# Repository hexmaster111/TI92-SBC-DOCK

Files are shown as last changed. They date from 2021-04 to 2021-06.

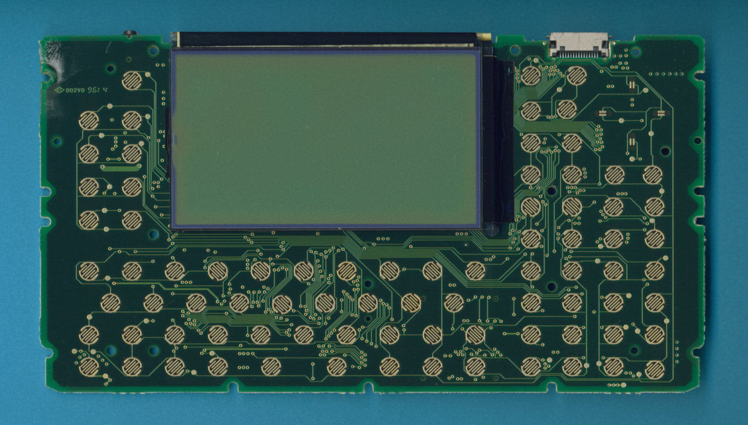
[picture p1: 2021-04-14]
TI-92_I0696_PCBA.jpg

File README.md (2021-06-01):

**NOTE**
The Zero version is not currently being worked on and is an unusable state

# TI92 - CM4

TODO
--------
- [ ] Whats gonna happon is im gonna get a 4 inch hdmi display and desolder the hdmi connector and add it to a ribbion cable and then add a connector to the pcb for hdmi to interface with that
- [ ] Add a SD card slot
- [x] Figure out what display to use
- [ ] Add a headphone port
- [x] Add a USB Hub
	- [ ] Route USB in a good way :wink:
- [x] Get a charge solution sorted
- [x] Figure out how the keyboard will work and talk to the pi
- [ ] TEST
- [ ] Write code for the ATTINY85 (aka power control chip)
	- [ ] ~~Find a better way to switch power?~~
 - [ ] Use the micro USB that is used for charging to also act as USB OTG for flashing the CM4
 - [ ] Figure out a low voltage cut off for the batCell+ line
 - [ ] Calculate R4 on the charge chip
 - [ ] Make sure all the components will fit in the case with there given footprints
	 - [ ] Measure for LEDS
		 - [ ] Drill Holes for indicators
		 - [ ] Make a nice overlay for indicators 
	 - [ ] Measure for USB Connections
		 - [ ] Modify case

Display
----------
The display being used is a 4 inch SPI display by waveshare and is connected with a pin header, I still have to get the part and check for fitmint for sure, but [this](https://www.waveshare.com/4inch-RPi-LCD-C.htm) looks prmissing

for the display, install accoring to waveshare https://www.waveshare.com/wiki/4inch_HDMI_LCD and deleate all the vc4 overlays and it works (somehow)

Battery Charging
----------
For charging two 18650s I'm using the BQ25887RGET Chip by TI. This chip should have enough current to keep the batteries charged in use. For power input I'm using a Micro USB 

USB Hub
-----------
For a USB hub I'm using the TUSB4041l by Texas instruments, this chip supports 4 downstream ports and 1 upstream, the upstream port is wired directly into the CM4's USB data lines. There are two ports that are connected to standard USB connectors. 

There is also one USB port left unused on the board for internal modifications later on. 

To Get this chip to work, I had to add a 3.3v power supply capable of suppling more current then the pi could, and added the +3.3 High Current Global net. 

To Get this chip to work, I had to add a 1v power supply capable of suppling more current then the pi could, and added the +1 Global net.

Making the keyboard work
----------------------------------
For a keyboard controller I chose to use a 5K5126 which is a programable keyboard controller that supports arbitrary key mapping along with macros and this is all done with a graphical program and uploaded to the keyboard. 
After uploading the matrix and stuff to the controller the idea is to then solder JP2 & JP3. This will then allow the keyboard to communicate with the hub controller and then into the CM4 modal
**note:**  The keyboard controller has some GPIO we can use for a backlight or indicator LEDs, I need to check this out more. 

Power Control
--------
The +5v will go high after the ON button on the keyboard is pressed, this is done using an ATTINY85 and a latching relay, this is done so that I can use this for other single board computers in the future.  
Here is some pseudo code to help understand the idea
```
Use a pin on the pi as a way to know if the system is on and if that pin goes low we disconnect the battery from the 5v converter

if power=off & PowerButton=on //Turn on +5v rail (ColdBoot)
	SETPIN goes high
	wait(50ms)
	SETPIN goes low
	wait(1min)

if PiOnPin=low & power=on  //Shutdown pi after power on pin goes low
	RESETPIN high
	Wait(50ms)
	RESETPIN low

if PiOnPin=high & power=on & PowerButton=on //Force Shutdown 
	if PowerButton = held for 10 sec
		RESETPIN high
		Wait(50ms)
		RESETPIN low	
```

Things to Add Perhaps
---------------------------
- A pointing device
	- A track ball or other pointing device like [this](https://shop.pimoroni.com/products/trackball-breakout). 
	- Perhaps a trackpad
	- Use the Lock/Pinch key as a the key for mouse keys and use the D-Pad as the key mouse
- Some way to have a nice GPIO pin header behind a door for a clean look
- A new keyboard overlay for 2nd keys and the green diamond keys
- Custom keycaps?! (Clear injections would be cool for backlighting)
- Perhaps a ti-92 plus emulator for it (just for fun)

Credits
------
I got the PCB and keyboard layout and matrix diagram from [here](https://github.com/ccadic/TI92-revive). 
Everything else was from the Digi key parts repo or I made.

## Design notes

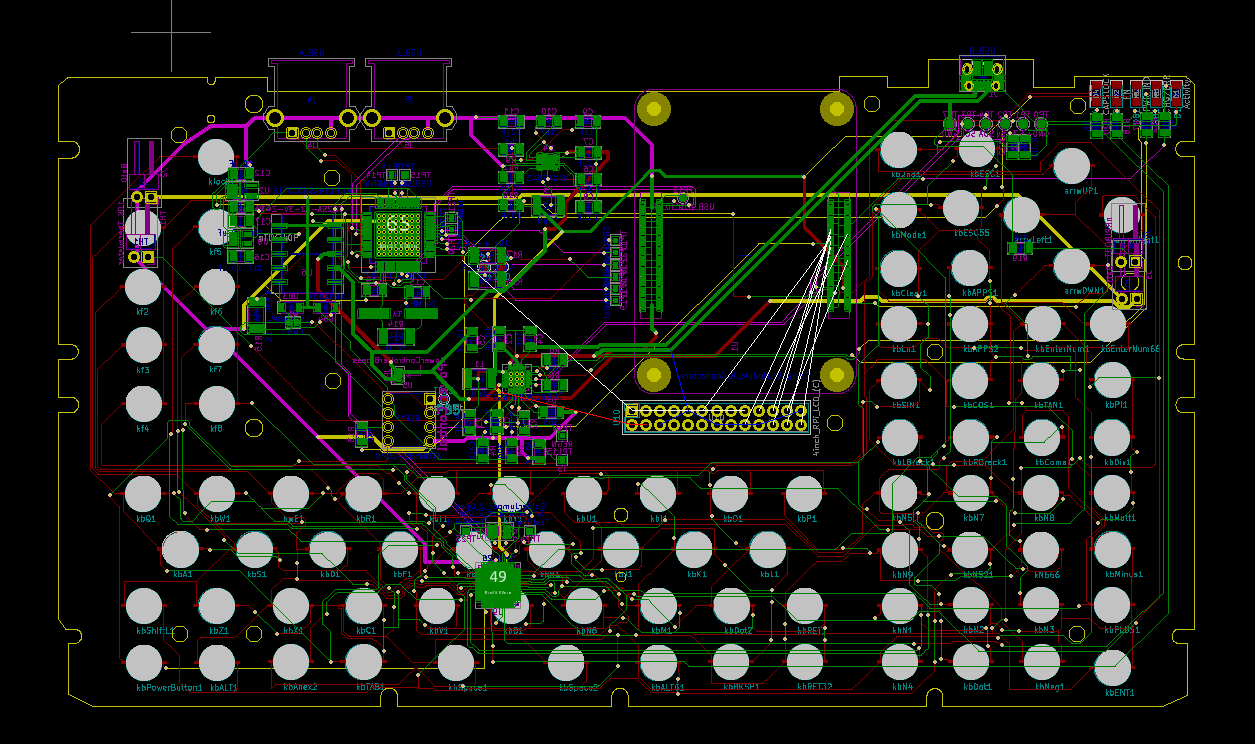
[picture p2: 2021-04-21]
CurrentProgress.PNG

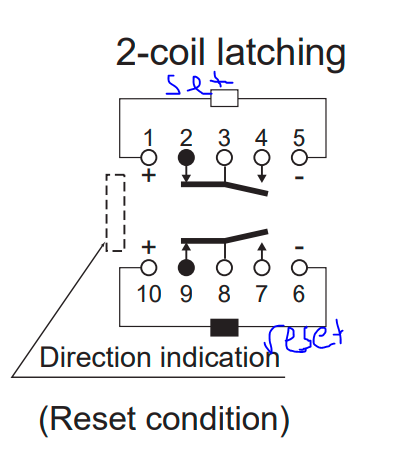
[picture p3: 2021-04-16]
CM4/DataSheets/RelaySnipFromDatasheet.PNG

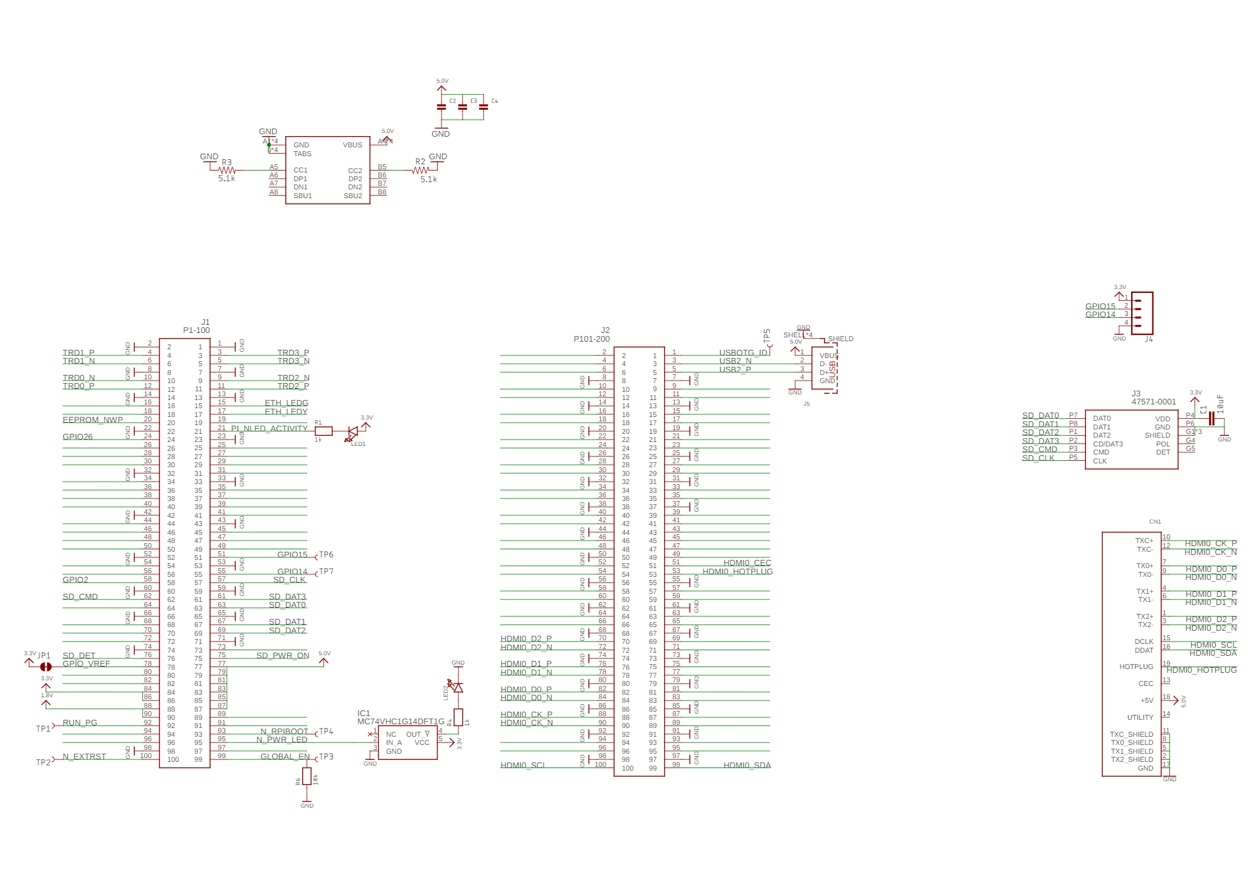
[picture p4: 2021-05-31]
CM4/DataSheets/simpleCM4 carrerer.png

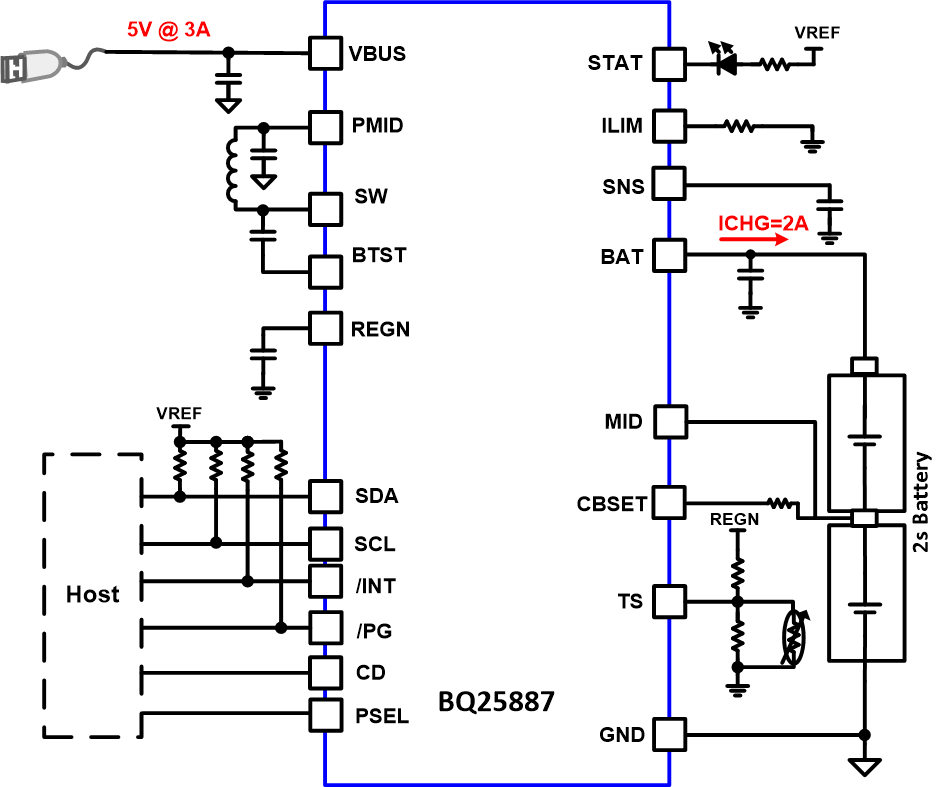
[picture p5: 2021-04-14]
CM4/DataSheets/fbd_slusd89b.gif

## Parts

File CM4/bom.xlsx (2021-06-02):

B2B-PH-K-S(LF)(SN)
PHR-2
SPH-002T-P0.5S
https://www.digikey.com/en/products/detail/bourns-inc/CC453232A-1R0KL/12756230
https://www.digikey.com/en/products/detail/texas-instruments/BQ25887RGET/10270194
10103594-0001LF | usb con
 |  |  | Magic Two Transistors for power
TPS61230DRCR (https://www.mouser.com/ProductDetail/Texas-Instruments/TPS61230DRCR?qs=p08Uhw9w2Fyn7hRbmC7n5A%3D%3D) |  |  | https://www.digikey.com/en/products/detail/rohm-semiconductor/EMH61T2R/5721184
 |  |  | Transistors for lcd
Power Control Tranistor |  |  | https://www.digikey.com/en/products/detail/on-semiconductor/NUS2401SNT1G/13442745
https://www.digikey.com/en/products/detail/goford-semiconductor/G6N02L/13664832
 |  |  | usb controller powersupply
https://www.digikey.com/en/products/detail/stewart-connector/SS-52100-001/7902377 |  |  | NCP114ASN330T1G
 |  |  | Usb controler
TQ2SA-L2-3V (https://www.mouser.com/ProductDetail/Panasonic-Industrial-Devices/TQ2SA-L2-3V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)
 |  |  | TUSB4041I-Q1 Four-Port USB 2.0 Hub | https://www.digikey.com/en/products/detail/citizen-finedevice-co-ltd/HCM4924000000ABJT/284293
 |  |  |  | Crystle
 |  | The display | 1v regulator
 |  | https://www.waveshare.com/4inch-RPi-LCD-C.htm | https://www.digikey.com/en/products/detail/texas-instruments/TLV74010PDBVR/12642176
 | Fan
 | https://www.digikey.com/en/products/detail/delta-electronics/BSB0205HP-00EFG/11201159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
 | sd con
 | https://www.digikey.com/en/products/detail/molex/5031821852/4693482

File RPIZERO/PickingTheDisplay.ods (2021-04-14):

Display | Width IN | Height IN | Angle size | Resulutinon | Price | Connection | Link
Stock 92+ | 3.5 | 1.9 | ~4 | low | free | in the calc
Pocket chip | 3.875 | 2.25 | ~4.5 | 480*272 | NA | Magic | Nope >.<
Ebay #1 | 3.85 | 2.28 | ~4 | 800*480 | 52.39 | HDMI | https://www.ebay.com/itm/Raspberry-Pi-4-Touchscreen-with-Case-Fan-4-inch-IPS-Touch-Screen-LCD-Display/363316412604

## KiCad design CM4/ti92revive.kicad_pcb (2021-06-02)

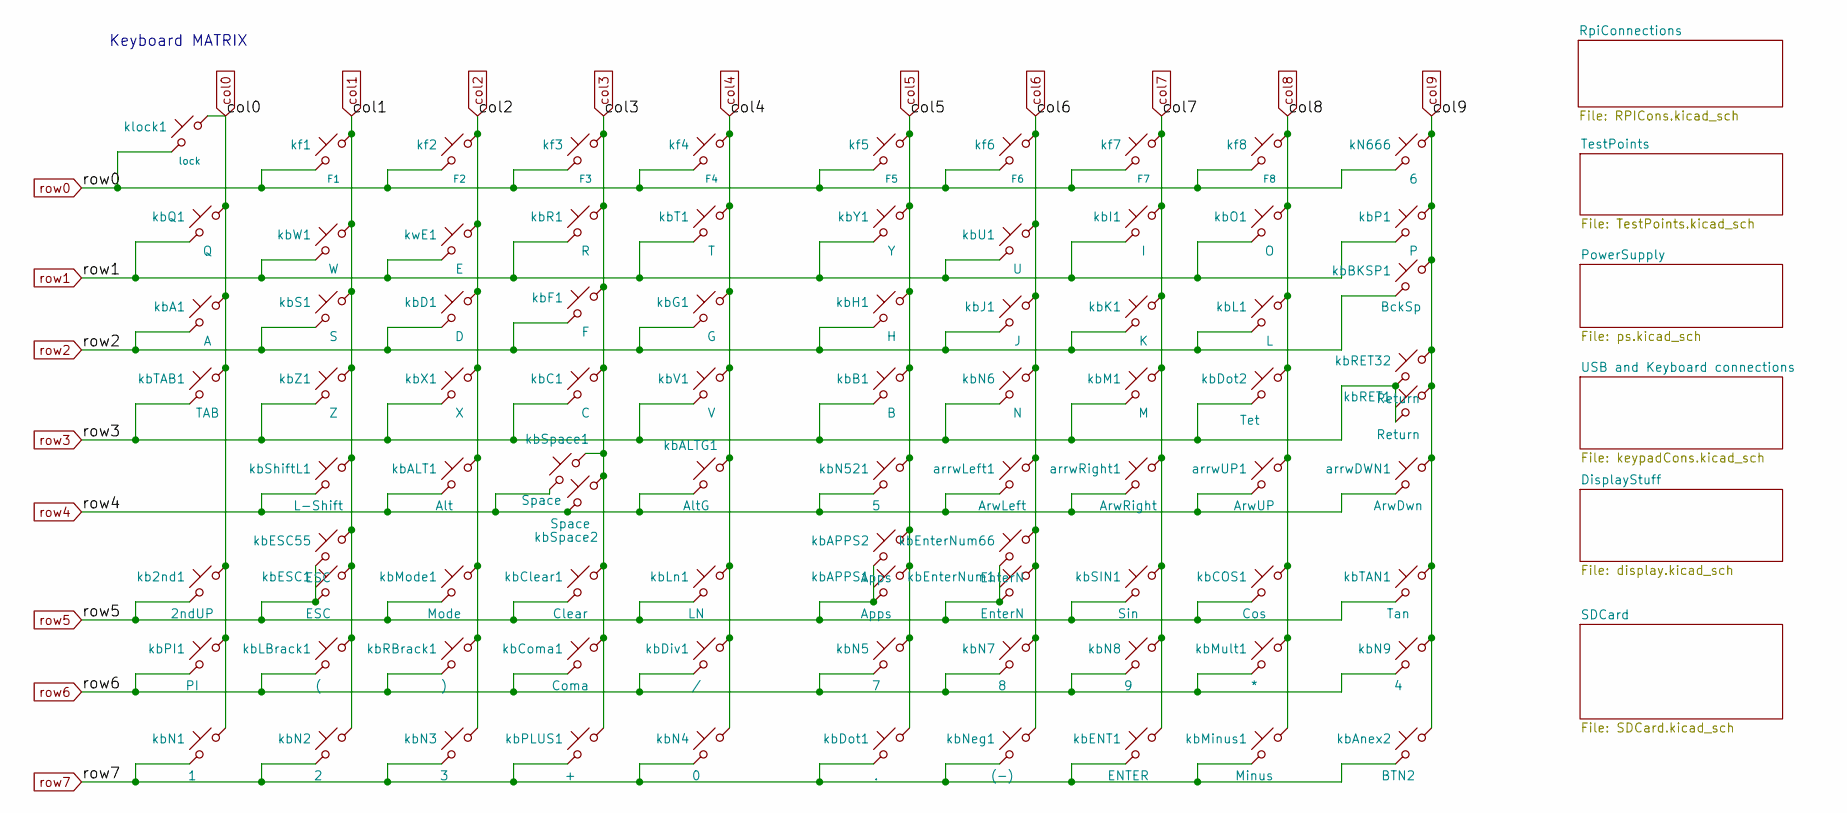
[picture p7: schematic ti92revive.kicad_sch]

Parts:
arrwDWN1: ArwDwn; Kbpad
arrwLeft1: ArwLeft; Kbpad
arrwRight1: ArwRight; Kbpad
arrwUP1: ArwUP; Kbpad
kN666: 6; Kbpad
kb2nd1: 2ndUP; Kbpad
kbA1: A; Kbpad
kbALT1: Alt; Kbpad
kbALTG1: AltG; Kbpad
kbAPPS1, kbAPPS2: Apps; Kbpad
kbAnex2: BTN2; Kbpad
kbB1: B; Kbpad
kbBKSP1: BckSp; Kbpad
kbC1: C; Kbpad
kbCOS1: Cos; Kbpad
kbClear1: Clear; Kbpad
kbComa1: Coma; Kbpad
kbD1: D; Kbpad
kbDiv1: /; Kbpad
kbDot1: .; Kbpad
kbDot2: Tet; Kbpad
kbENT1: ENTER; Kbpad
kbESC1, kbESC55: ESC; Kbpad
kbEnterNum1, kbEnterNum66: EnterN; Kbpad
kbF1: F; Kbpad
kbG1: G; Kbpad
kbH1: H; Kbpad
kbI1: I; Kbpad
kbJ1: J; Kbpad
kbK1: K; Kbpad
kbL1: L; Kbpad
kbLBrack1: (; Kbpad
kbLn1: LN; Kbpad
kbM1: M; Kbpad
kbMinus1: Minus; Kbpad
kbMode1: Mode; Kbpad
kbMult1: *; Kbpad
kbN1: 1; Kbpad
kbN2: 2; Kbpad
kbN3: 3; Kbpad
kbN4: 0; Kbpad
kbN5: 7; Kbpad
kbN6: N; Kbpad
kbN7: 8; Kbpad
kbN8: 9; Kbpad
kbN9: 4; Kbpad
kbN521: 5; Kbpad
kbNeg1: (-); Kbpad
kbO1: O; Kbpad
kbP1: P; Kbpad
kbPI1: PI; Kbpad
kbPLUS1: +; Kbpad
kbQ1: Q; Kbpad
kbR1: R; Kbpad
kbRBrack1: ); Kbpad
kbRET1, kbRET32: Return; Kbpad
kbS1: S; Kbpad
kbSIN1: Sin; Kbpad
kbShiftL1: L-Shift; Kbpad
kbSpace1, kbSpace2: Space; Kbpad
kbT1: T; Kbpad
kbTAB1: TAB; Kbpad
kbTAN1: Tan; Kbpad
kbU1: U; Kbpad
kbV1: V; Kbpad
kbW1: W; Kbpad
kbX1: X; Kbpad
kbY1: Y; Kbpad
kbZ1: Z; Kbpad
kf1: F1; Kbpad
kf2: F2; Kbpad
kf3: F3; Kbpad
kf4: F4; Kbpad
kf5: F5; Kbpad
kf6: F6; Kbpad
kf7: F7; Kbpad
kf8: F8; Kbpad
klock1: lock; Kbpad
kwE1: E; Kbpad

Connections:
col0: kb2nd1.1, kbA1.1, kbN1.1, kbPI1.1, kbQ1.1, kbTAB1.1, klock1.1; also elsewhere on the board
col1: kbESC1.1, kbESC55.1, kbLBrack1.1, kbN2.1, kbS1.1, kbShiftL1.1, kbW1.1, kbZ1.1, kf1.1; also elsewhere on the board
col2: kbALT1.1, kbD1.1, kbMode1.1, kbN3.1, kbRBrack1.1, kbX1.1, kf2.1, kwE1.1; also elsewhere on the board
col3: kbC1.1, kbClear1.1, kbComa1.1, kbF1.1, kbPLUS1.1, kbR1.1, kbSpace1.1, kbSpace2.1, kf3.1; also elsewhere on the board
col4: kbALTG1.1, kbDiv1.1, kbG1.1, kbLn1.1, kbN4.1, kbT1.1, kbV1.1, kf4.1; also elsewhere on the board
col5: kbAPPS1.1, kbAPPS2.1, kbB1.1, kbDot1.1, kbH1.1, kbN5.1, kbN521.1, kbY1.1, kf5.1; also elsewhere on the board
col6: arrwLeft1.1, kbEnterNum1.1, kbEnterNum66.1, kbJ1.1, kbN6.1, kbN7.1, kbNeg1.1, kbU1.1, kf6.1; also elsewhere on the board
col7: arrwRight1.1, kbENT1.1, kbI1.1, kbK1.1, kbM1.1, kbN8.1, kbSIN1.1, kf7.1; also elsewhere on the board
col8: arrwUP1.1, kbCOS1.1, kbDot2.1, kbL1.1, kbMinus1.1, kbMult1.1, kbO1.1, kf8.1; also elsewhere on the board
col9: arrwDWN1.1, kN666.1, kbAnex2.1, kbBKSP1.1, kbN9.1, kbP1.1, kbRET1.1, kbRET32.1, kbTAN1.1; also elsewhere on the board
row0: kN666.2, kf1.2, kf2.2, kf3.2, kf4.2, kf5.2, kf6.2, kf7.2, kf8.2, klock1.2; also elsewhere on the board
row1: kbI1.2, kbO1.2, kbP1.2, kbQ1.2, kbR1.2, kbT1.2, kbU1.2, kbW1.2, kbY1.2, kwE1.2; also elsewhere on the board
row2: kbA1.2, kbBKSP1.2, kbD1.2, kbF1.2, kbG1.2, kbH1.2, kbJ1.2, kbK1.2, kbL1.2, kbS1.2; also elsewhere on the board
row3: kbB1.2, kbC1.2, kbDot2.2, kbM1.2, kbN6.2, kbRET1.2, kbRET32.2, kbTAB1.2, kbV1.2, kbX1.2, kbZ1.2; also elsewhere on the board
row4: arrwDWN1.2, arrwLeft1.2, arrwRight1.2, arrwUP1.2, kbALT1.2, kbALTG1.2, kbN521.2, kbShiftL1.2, kbSpace1.2, kbSpace2.2; also elsewhere on the board
row5: kb2nd1.2, kbAPPS1.2, kbAPPS2.2, kbCOS1.2, kbClear1.2, kbESC1.2, kbESC55.2, kbEnterNum1.2, kbEnterNum66.2, kbLn1.2, kbMode1.2, kbSIN1.2, kbTAN1.2; also elsewhere on the board
row6: kbComa1.2, kbDiv1.2, kbLBrack1.2, kbMult1.2, kbN5.2, kbN7.2, kbN8.2, kbN9.2, kbPI1.2, kbRBrack1.2; also elsewhere on the board
row7: kbAnex2.2, kbDot1.2, kbENT1.2, kbMinus1.2, kbN1.2, kbN2.2, kbN3.2, kbN4.2, kbNeg1.2, kbPLUS1.2; also elsewhere on the board

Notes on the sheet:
Keyboard MATRIX

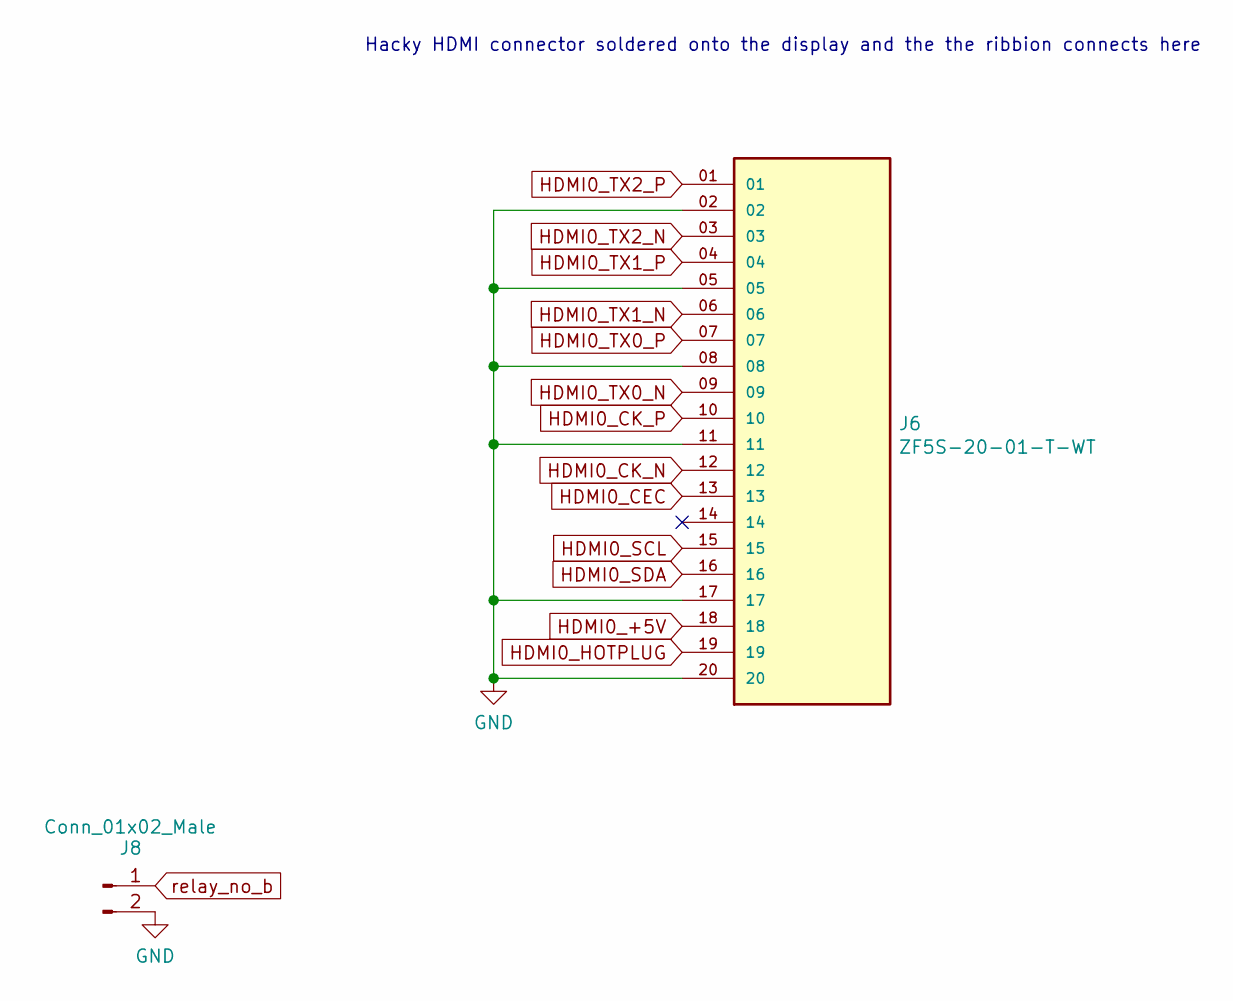
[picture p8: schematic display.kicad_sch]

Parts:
J6: ZF5S-20-01-T-WT; SAMTEC_ZF5S-20-01-T-WT
J8: Conn_01x02_Male; PinHeader_1x02_P1.00mm_Vertical

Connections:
Earth_Clean: J6.02, J6.05, J6.08, J6.11, J6.17, J6.20, J8.2; also elsewhere on the board
HDMI0_+5V: J6.18
HDMI0_CEC: J6.13; also elsewhere on the board
HDMI0_CK_N: J6.12; also elsewhere on the board
HDMI0_CK_P: J6.10; also elsewhere on the board
HDMI0_HOTPLUG: J6.19; also elsewhere on the board
HDMI0_SCL: J6.15; also elsewhere on the board
HDMI0_SDA: J6.16; also elsewhere on the board
HDMI0_TX0_N: J6.09; also elsewhere on the board
HDMI0_TX0_P: J6.07; also elsewhere on the board
HDMI0_TX1_N: J6.06; also elsewhere on the board
HDMI0_TX1_P: J6.04; also elsewhere on the board
HDMI0_TX2_N: J6.03; also elsewhere on the board
HDMI0_TX2_P: J6.01; also elsewhere on the board
relay_no_b: J8.1; also elsewhere on the board

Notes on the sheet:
Hacky HDMI connector soldered onto the display and the the ribbion connects here

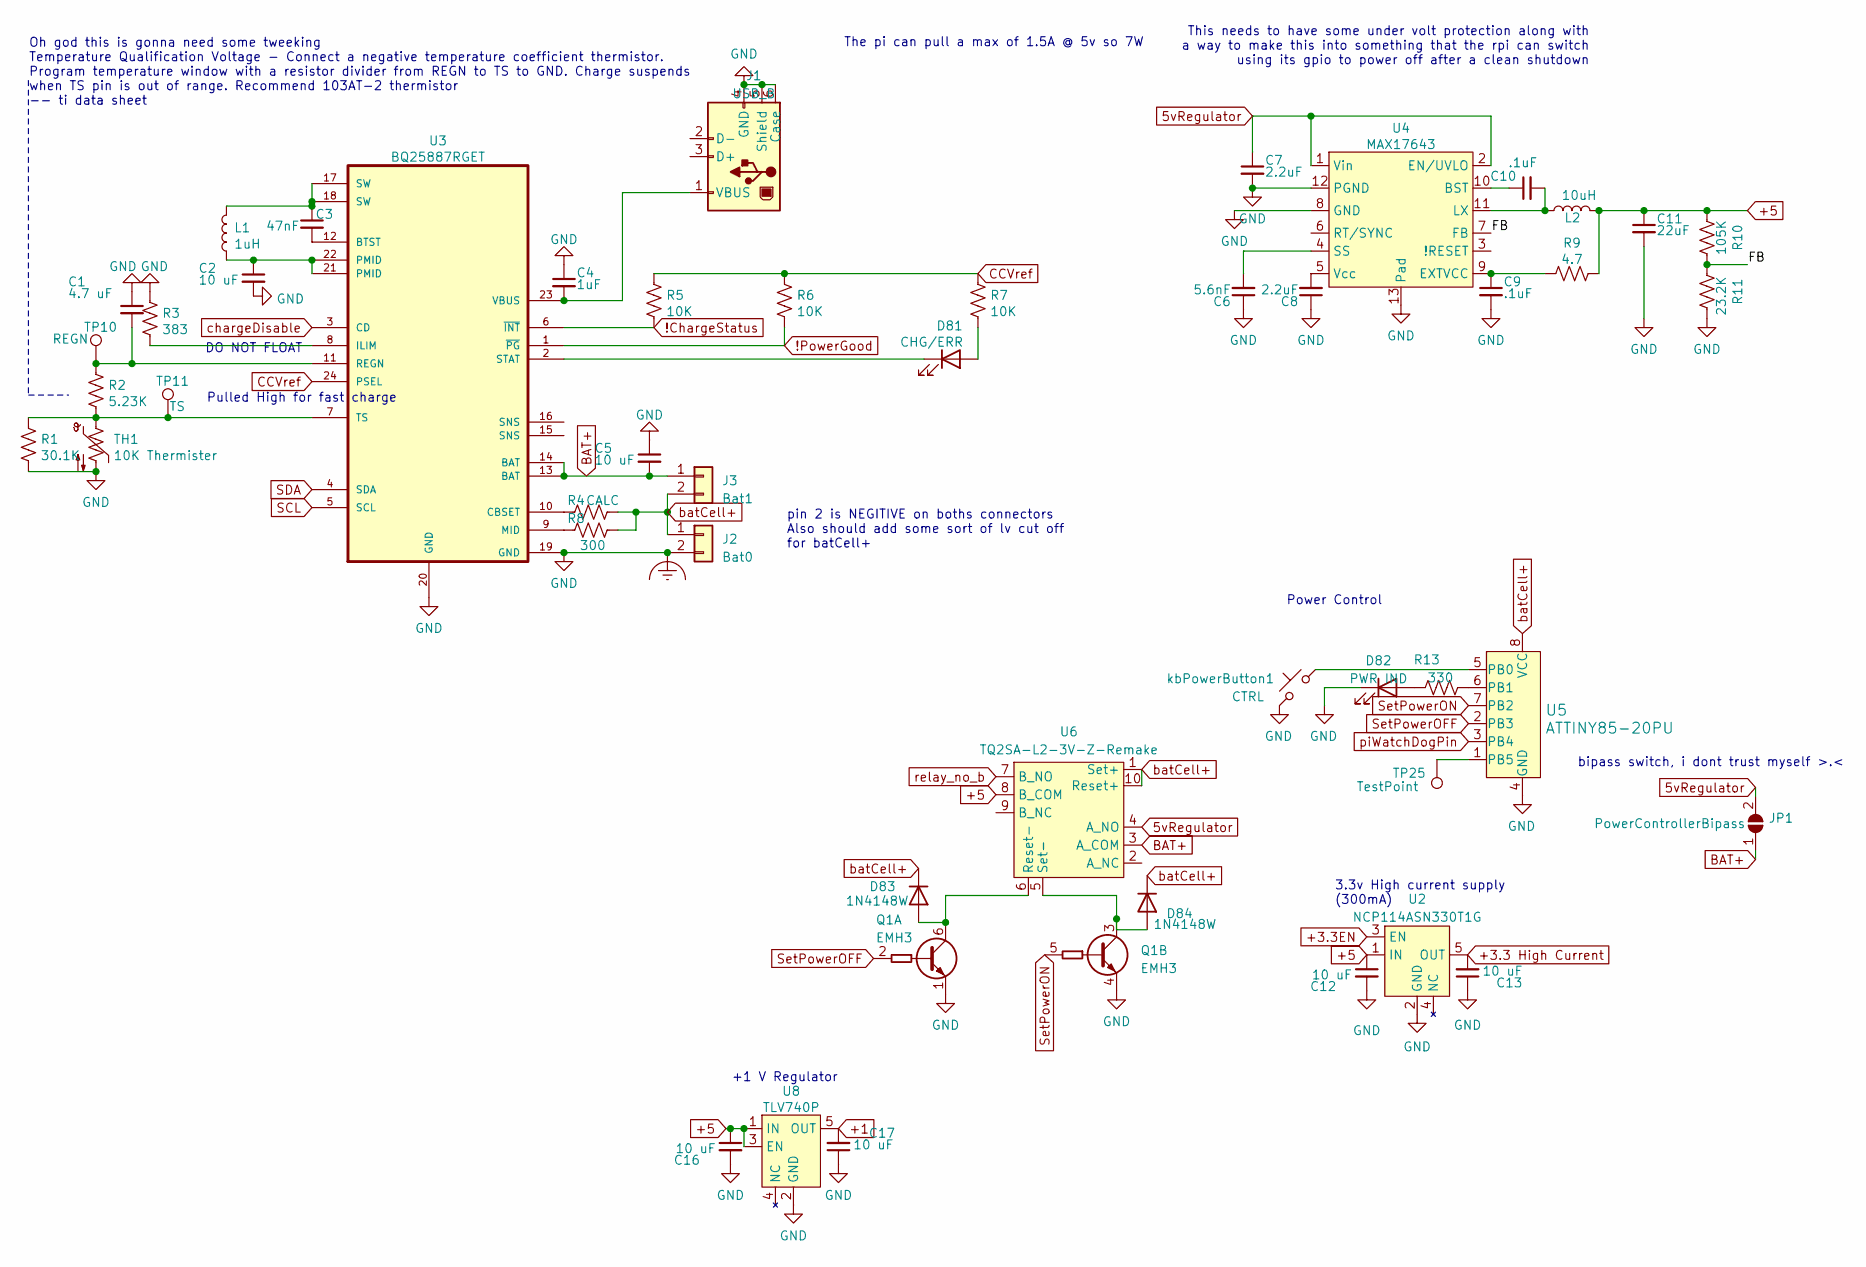
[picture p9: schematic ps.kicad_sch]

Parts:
C1: 4.7 uF; C_1206_3216Metric
C2, C5, C12, C13, C16, C17: 10 uF; C_1206_3216Metric
C3: 47nF; C_1206_3216Metric
C4: 1uF; C_1206_3216Metric
C6: 5.6nF; C_1206_3216Metric
C7, C8: 2.2uF; C_1206_3216Metric
C9, C10: .1uF; C_1206_3216Metric
C11: 22uF; C_1206_3216Metric
D81: CHG/ERR; LED_1206_3216Metric_Pad1.42x1.75mm_HandSolder
D82: PWR IND; LED_1206_3216Metric_Pad1.42x1.75mm_HandSolder
D83, D84: 1N4148W; D_SOD-123
J1: USB_B; USB_Micro-B_Amphenol_10103594-0001LF_Horizontal
J2: Bat0; PinHeader_1x02_P2.54mm_Horizontal
J3: Bat1; PinHeader_1x02_P2.54mm_Horizontal
JP1: PowerControllerBipass; SolderJumper-2_P1.3mm_Open_RoundedPad1.0x1.5mm
L1: 1uH; L_1812_4532Metric
L2: 10uH; L_1812_4532Metric
Q1: EMH3; SOT-563
R1: 30.1K; R_1206_3216Metric
R2: 5.23K; R_1206_3216Metric
R3: 383; R_1206_3216Metric
R4: CALC; R_1206_3216Metric
R5, R6, R7: 10K; R_1206_3216Metric
R8: 300; R_1206_3216Metric
R9: 4.7; R_1206_3216Metric
R10: 105K; R_1206_3216Metric
R11: 23.2K; R_1206_3216Metric
R13: 330; R_1206_3216Metric
TH1: 10K Thermister; PinHeader_1x02_P2.54mm_Horizontal
TP10: REGN; TestPoint_Pad_1.0x1.0mm
TP11: TS; TestPoint_Pad_1.0x1.0mm
TP25: TestPoint; TestPoint_Pad_D1.0mm
U2: NCP114ASN330T1G; TSOT-23-5_HandSoldering
U3: BQ25887RGET; VQFN-24-1EP_4x4mm_P0.5mm_EP2.45x2.45mm_ThermalVias
U4: MAX17643; TDFN-12_3x3mm_P0.5mm
U5: ATTINY85-20PU; DIP-8_W7.62mm; MPN ATTINY85-20PU; Digi-Key_PN ATTINY85-20PU-ND
U6: TQ2SA-L2-3V-Z-Remake; TQ2SA-L2-3V-Z
U8: TLV740P; SOT-23-5_HandSoldering
kbPowerButton1: CTRL; Kbpad

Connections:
5vRegulator: C7.1, JP1.2 (B), U4.1 (Vin), U4.2 (EN/UVLO), U6.4 (A_NO)
!ChargeStatus: R5.1, U3.6 (~INT)
!PowerGood: R6.1, U3.1 (~PG)
+1: C17.2, U8.5 (OUT); also elsewhere on the board
+1.8: U2.3 (EN); also elsewhere on the board
+3.3 High Current: C13.2, U2.5 (OUT); also elsewhere on the board
+5: C11.1, C12.1, C16.1, L2.2, R9.2, R10.1, U2.1 (IN), U6.8 (B_COM), U8.1 (IN), U8.3 (EN); also elsewhere on the board
/PowerSupply/FB: R10.2, R11.1, U4.7 (FB)
BAT+: C5.2, J3.1, JP1.1 (A), U3.13 (BAT), U3.14 (BAT), U6.3 (A_COM)
CCVref: R5.2, R6.2, R7.2, U3.24 (PSEL)
Earth_Clean: C1.1, C2.2, C4.1, C5.1, C6.1, C7.2, C8.1, C9.2, C11.2, C12.2, C13.1, C16.2, C17.1, D82.1 (K), J1.4 (GND), J1.5 (Shield), J1.6 (Case), J2.2, Q1.1 (E1), Q1.4 (E2), R1.1, R3.1, R11.2, TH1.2, U2.2 (GND), U3.19 (GND), U3.20 (GND), U4.8 (GND), U4.12 (PGND), U4.13 (Pad), U5.4 (GND), U8.2 (GND), kbPowerButton1.2; also elsewhere on the board
unnamed: C1.2, R2.2, TP10.1, U3.11 (REGN)
unnamed: C2.1, L1.1, U3.21 (PMID), U3.22 (PMID)
unnamed: C3.1, L1.2, U3.17 (SW), U3.18 (SW)
unnamed: C3.2, U3.12 (BTST)
unnamed: C4.2, J1.1 (VBUS), U3.23 (VBUS)
unnamed: C6.2, U4.4 (SS)
unnamed: C8.2, U4.5 (Vcc)
unnamed: C9.1, R9.1, U4.9 (EXTVCC)
unnamed: C10.1, U4.10 (BST)
unnamed: C10.2, L2.1, U4.11 (LX)
unnamed: D81.1 (K), U3.2 (STAT)
unnamed: D81.2 (A), R7.1
unnamed: D82.2 (A), R13.2
unnamed: D83.2 (A), Q1.6 (C1), U6.6 (Reset-)
unnamed: D84.2 (A), Q1.3 (C2), U6.5 (Set-)
unnamed: R1.2, R2.1, TH1.1, TP11.1, U3.7 (TS)
unnamed: R3.2, U3.8 (ILIM)
unnamed: R4.2, U3.10 (CBSET)
unnamed: R8.2, U3.9 (MID)
unnamed: R13.1, U5.6 (PB1)
unnamed: TP25.1, U5.1 (PB5)
unnamed: U5.5 (PB0), kbPowerButton1.1
SCL: U3.5 (SCL); also elsewhere on the board
SDA: U3.4 (SDA); also elsewhere on the board
SetPowerOFF: Q1.2 (B1), U5.2 (PB3)
SetPowerON: Q1.5 (B2), U5.7 (PB2)
batCell+: D83.1 (K), D84.1 (K), J2.1, J3.2, R4.1, R8.1, U5.8 (VCC), U6.1 (Set+), U6.10 (Reset+)
chargeDisable: U3.3 (CD)
piWatchDogPin: U5.3 (PB4); also elsewhere on the board
relay_no_b: U6.7 (B_NO); also elsewhere on the board

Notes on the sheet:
Oh god this is gonna need some tweeking Temperature Qualification Voltage - Connect a negative temperature coefficient thermistor. Program temperature window with a resistor divider from REGN to TS to GND. Charge suspends when TS pin is out of range. Recommend 103AT-2 thermistor -- ti data sheet
DO NOT FLOAT
Pulled High for fast charge
pin 2 is NEGITIVE on boths connectors Also should add some sort of lv cut off for batCell+
+1 V Regulator
The pi can pull a max of 1.5A @ 5v so 7W
3.3v High current supply (300mA)
Power Control
This needs to have some under volt protection along with a way to make this into something that the rpi can switch using its gpio to power off after a clean shutdown
bipass switch, i dont trust myself >.<

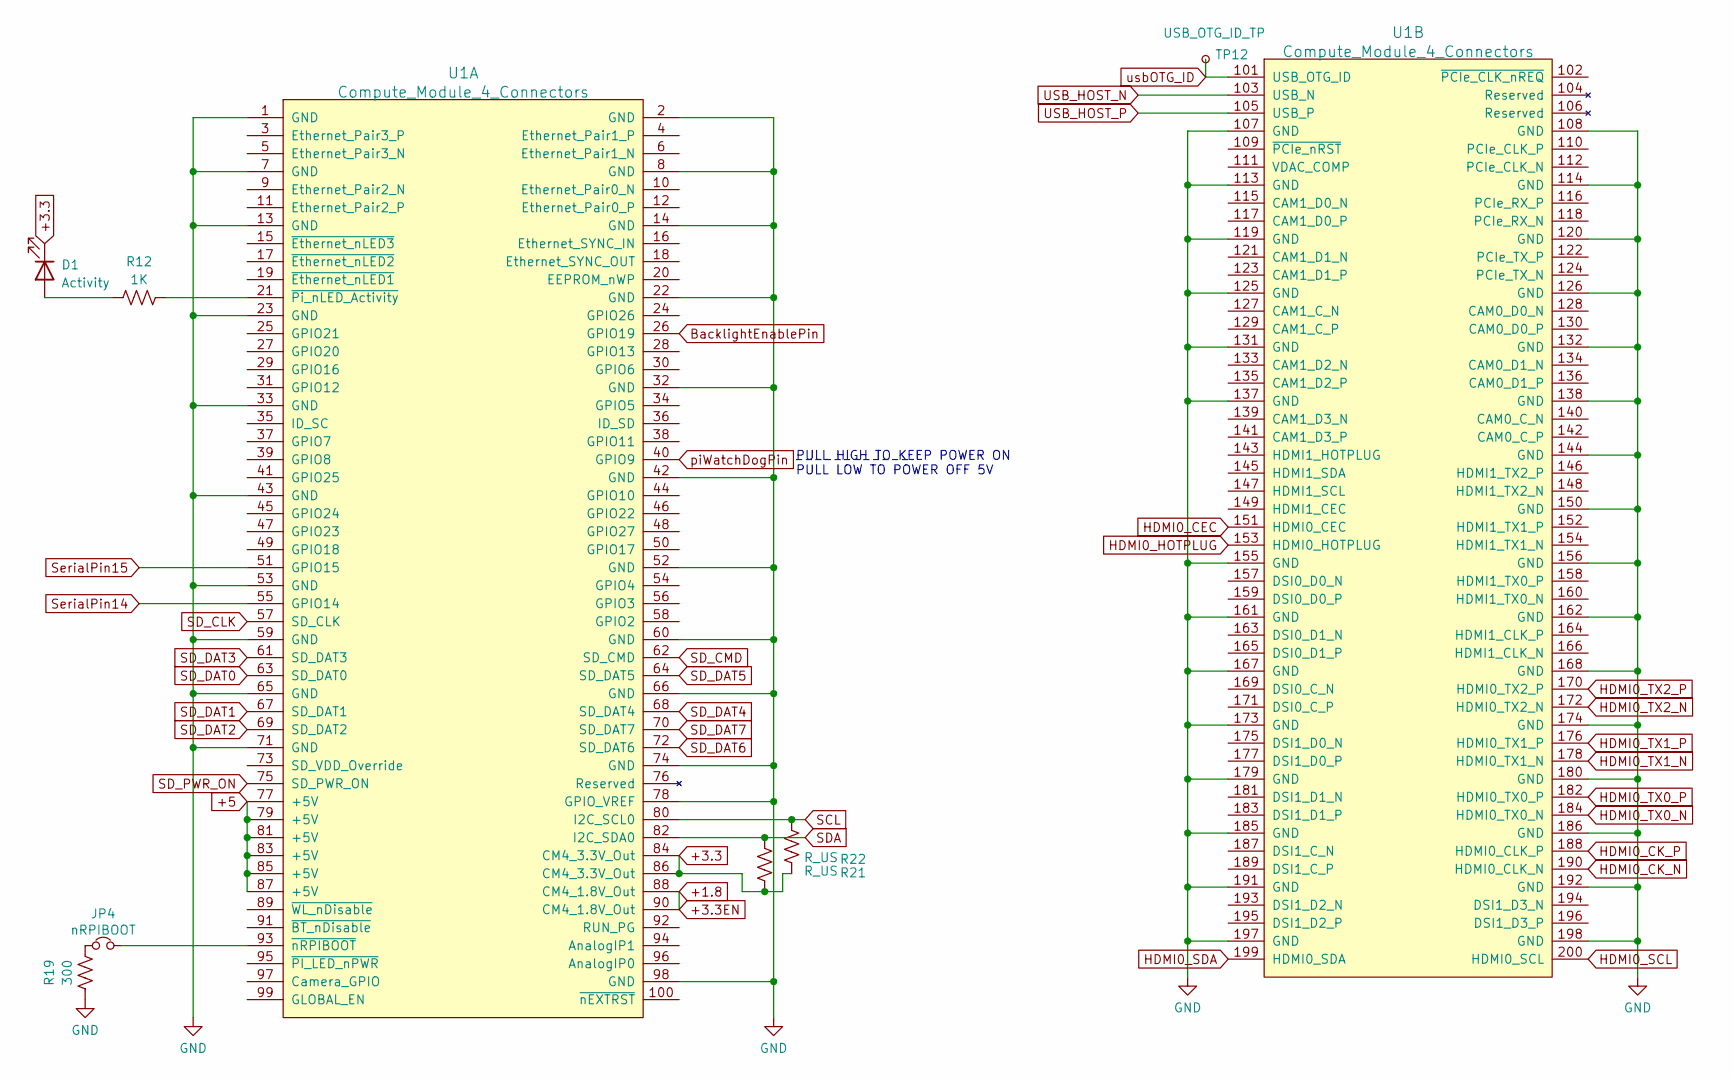
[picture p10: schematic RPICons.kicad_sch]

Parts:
D1: Activity; LED_1206_3216Metric_Pad1.42x1.75mm_HandSolder
JP4: nRPIBOOT; PinHeader_1x02_P2.54mm_Horizontal
R12: 1K; R_1206_3216Metric
R19: 300; R_1206_3216Metric
R21, R22: R_US; R_1206_3216Metric
TP12: USB_OTG_ID_TP; TestPoint_Pad_D1.0mm
U1: Compute_Module_4_Connectors; Raspberry-Pi-4-Compute-Module

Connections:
+1.8: U1.88 (CM4_1.8V_Out), U1.90 (CM4_1.8V_Out); also elsewhere on the board
+3.3: D1.1 (K), R21.2, R22.2, U1.84 (CM4_3.3V_Out), U1.86 (CM4_3.3V_Out); also elsewhere on the board
+5: U1.77 (+5V), U1.79 (+5V), U1.81 (+5V), U1.83 (+5V), U1.85 (+5V), U1.87 (+5V); also elsewhere on the board
BacklightEnablePin: U1.26 (GPIO19)
Earth_Clean: R19.1, U1.1 (GND), U1.2 (GND), U1.7 (GND), U1.8 (GND), U1.13 (GND), U1.14 (GND), U1.22 (GND), U1.23 (GND), U1.32 (GND), U1.33 (GND), U1.42 (GND), U1.43 (GND), U1.52 (GND), U1.53 (GND), U1.59 (GND), U1.60 (GND), U1.65 (GND), U1.66 (GND), U1.71 (GND), U1.74 (GND), U1.78 (GPIO_VREF), U1.98 (GND), U1.107 (GND), U1.108 (GND), U1.113 (GND), U1.114 (GND), U1.119 (GND), U1.120 (GND), U1.125 (GND), U1.126 (GND), U1.131 (GND), U1.132 (GND), U1.137 (GND), U1.138 (GND), U1.144 (GND), U1.150 (GND), U1.155 (GND), U1.156 (GND), U1.161 (GND), U1.162 (GND), U1.167 (GND), U1.168 (GND), U1.173 (GND), U1.174 (GND), U1.179 (GND), U1.180 (GND), U1.185 (GND), U1.186 (GND), U1.191 (GND), U1.192 (GND), U1.197 (GND), U1.198 (GND); also elsewhere on the board
HDMI0_CEC: U1.151 (HDMI0_CEC); also elsewhere on the board
HDMI0_CK_N: U1.190 (HDMI0_CLK_N); also elsewhere on the board
HDMI0_CK_P: U1.188 (HDMI0_CLK_P); also elsewhere on the board
HDMI0_HOTPLUG: U1.153 (HDMI0_HOTPLUG); also elsewhere on the board
HDMI0_SCL: U1.200 (HDMI0_SCL); also elsewhere on the board
HDMI0_SDA: U1.199 (HDMI0_SDA); also elsewhere on the board
HDMI0_TX0_N: U1.184 (HDMI0_TX0_N); also elsewhere on the board
HDMI0_TX0_P: U1.182 (HDMI0_TX0_P); also elsewhere on the board
HDMI0_TX1_N: U1.178 (HDMI0_TX1_N); also elsewhere on the board
HDMI0_TX1_P: U1.176 (HDMI0_TX1_P); also elsewhere on the board
HDMI0_TX2_N: U1.172 (HDMI0_TX2_N); also elsewhere on the board
HDMI0_TX2_P: U1.170 (HDMI0_TX2_P); also elsewhere on the board
unnamed: D1.2 (A), R12.1
unnamed: JP4.1, R19.2
unnamed: JP4.2, U1.93 (~nRPIBOOT)
unnamed: R12.2, U1.21 (~Pi_nLED_Activity)
SCL: R22.1, U1.80 (I2C_SCL0); also elsewhere on the board
SDA: R21.1, U1.82 (I2C_SDA0); also elsewhere on the board
SD_CLK: U1.57 (SD_CLK); also elsewhere on the board
SD_CMD: U1.62 (SD_CMD); also elsewhere on the board
SD_DAT0: U1.63 (SD_DAT0); also elsewhere on the board
SD_DAT1: U1.67 (SD_DAT1); also elsewhere on the board
SD_DAT2: U1.69 (SD_DAT2); also elsewhere on the board
SD_DAT3: U1.61 (SD_DAT3); also elsewhere on the board
SD_DAT4: U1.68 (SD_DAT4)
SD_DAT5: U1.64 (SD_DAT5)
SD_DAT6: U1.72 (SD_DAT6)
SD_DAT7: U1.70 (SD_DAT7)
SD_PWR_ON: U1.75 (SD_PWR_ON)
SerialPin14: U1.55 (GPIO14); also elsewhere on the board
SerialPin15: U1.51 (GPIO15); also elsewhere on the board
USB_HOST_N: U1.103 (USB_N); also elsewhere on the board
USB_HOST_P: U1.105 (USB_P); also elsewhere on the board
piWatchDogPin: U1.40 (GPIO9); also elsewhere on the board
usbOTG_ID: TP12.1, U1.101 (USB_OTG_ID)

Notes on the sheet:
PULL HIGH TO KEEP POWER ON PULL LOW TO POWER OFF 5V

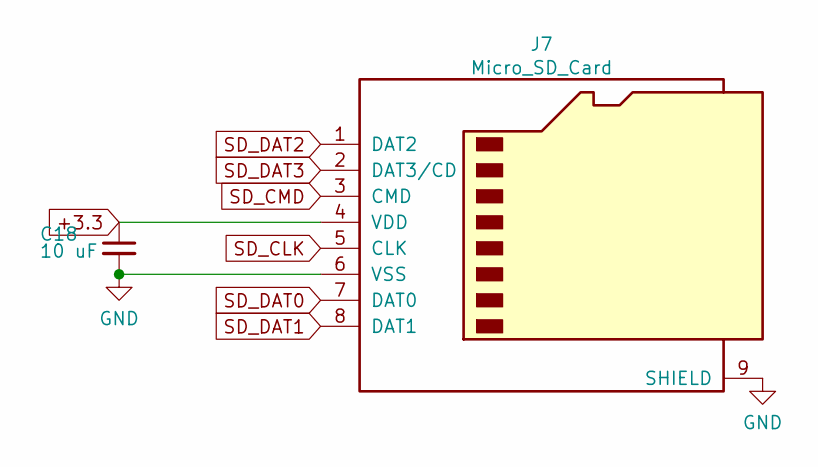
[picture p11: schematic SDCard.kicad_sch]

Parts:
C18: 10 uF; C_1206_3216Metric
J7: Micro_SD_Card; MOLEX_503182-1852

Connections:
+3.3: C18.1, J7.4 (VDD); also elsewhere on the board
Earth_Clean: C18.2, J7.6 (VSS), J7.9 (SHIELD); also elsewhere on the board
SD_CLK: J7.5 (CLK); also elsewhere on the board
SD_CMD: J7.3 (CMD); also elsewhere on the board
SD_DAT0: J7.7 (DAT0); also elsewhere on the board
SD_DAT1: J7.8 (DAT1); also elsewhere on the board
SD_DAT2: J7.1 (DAT2); also elsewhere on the board
SD_DAT3: J7.2 (DAT3/CD); also elsewhere on the board

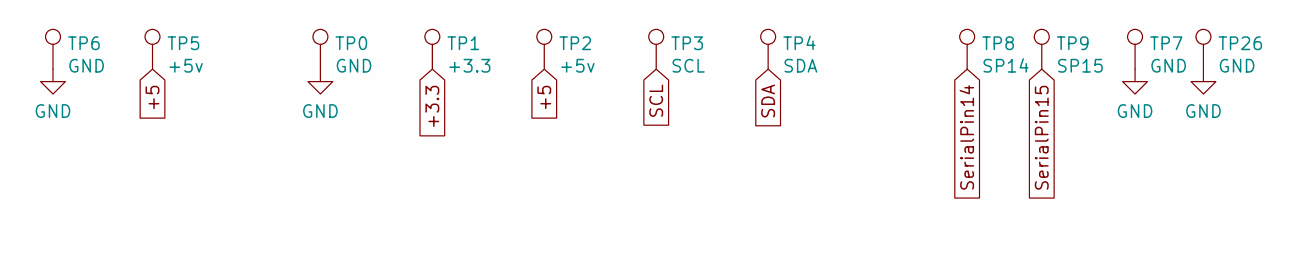
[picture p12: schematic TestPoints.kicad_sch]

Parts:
TP0, TP6, TP7, TP26: GND; TestPoint_Pad_D1.5mm
TP1: +3.3; TestPoint_Pad_D1.5mm
TP2, TP5: +5v; TestPoint_Pad_D1.5mm
TP3: SCL; TestPoint_Pad_D1.5mm
TP4: SDA; TestPoint_Pad_D1.5mm
TP8: SP14; TestPoint_Pad_D1.5mm
TP9: SP15; TestPoint_Pad_D1.5mm

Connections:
+3.3: TP1.1; also elsewhere on the board
+5: TP2.1, TP5.1; also elsewhere on the board
Earth_Clean: TP0.1, TP6.1, TP7.1, TP26.1; also elsewhere on the board
SCL: TP3.1; also elsewhere on the board
SDA: TP4.1; also elsewhere on the board
SerialPin14: TP8.1; also elsewhere on the board
SerialPin15: TP9.1; also elsewhere on the board

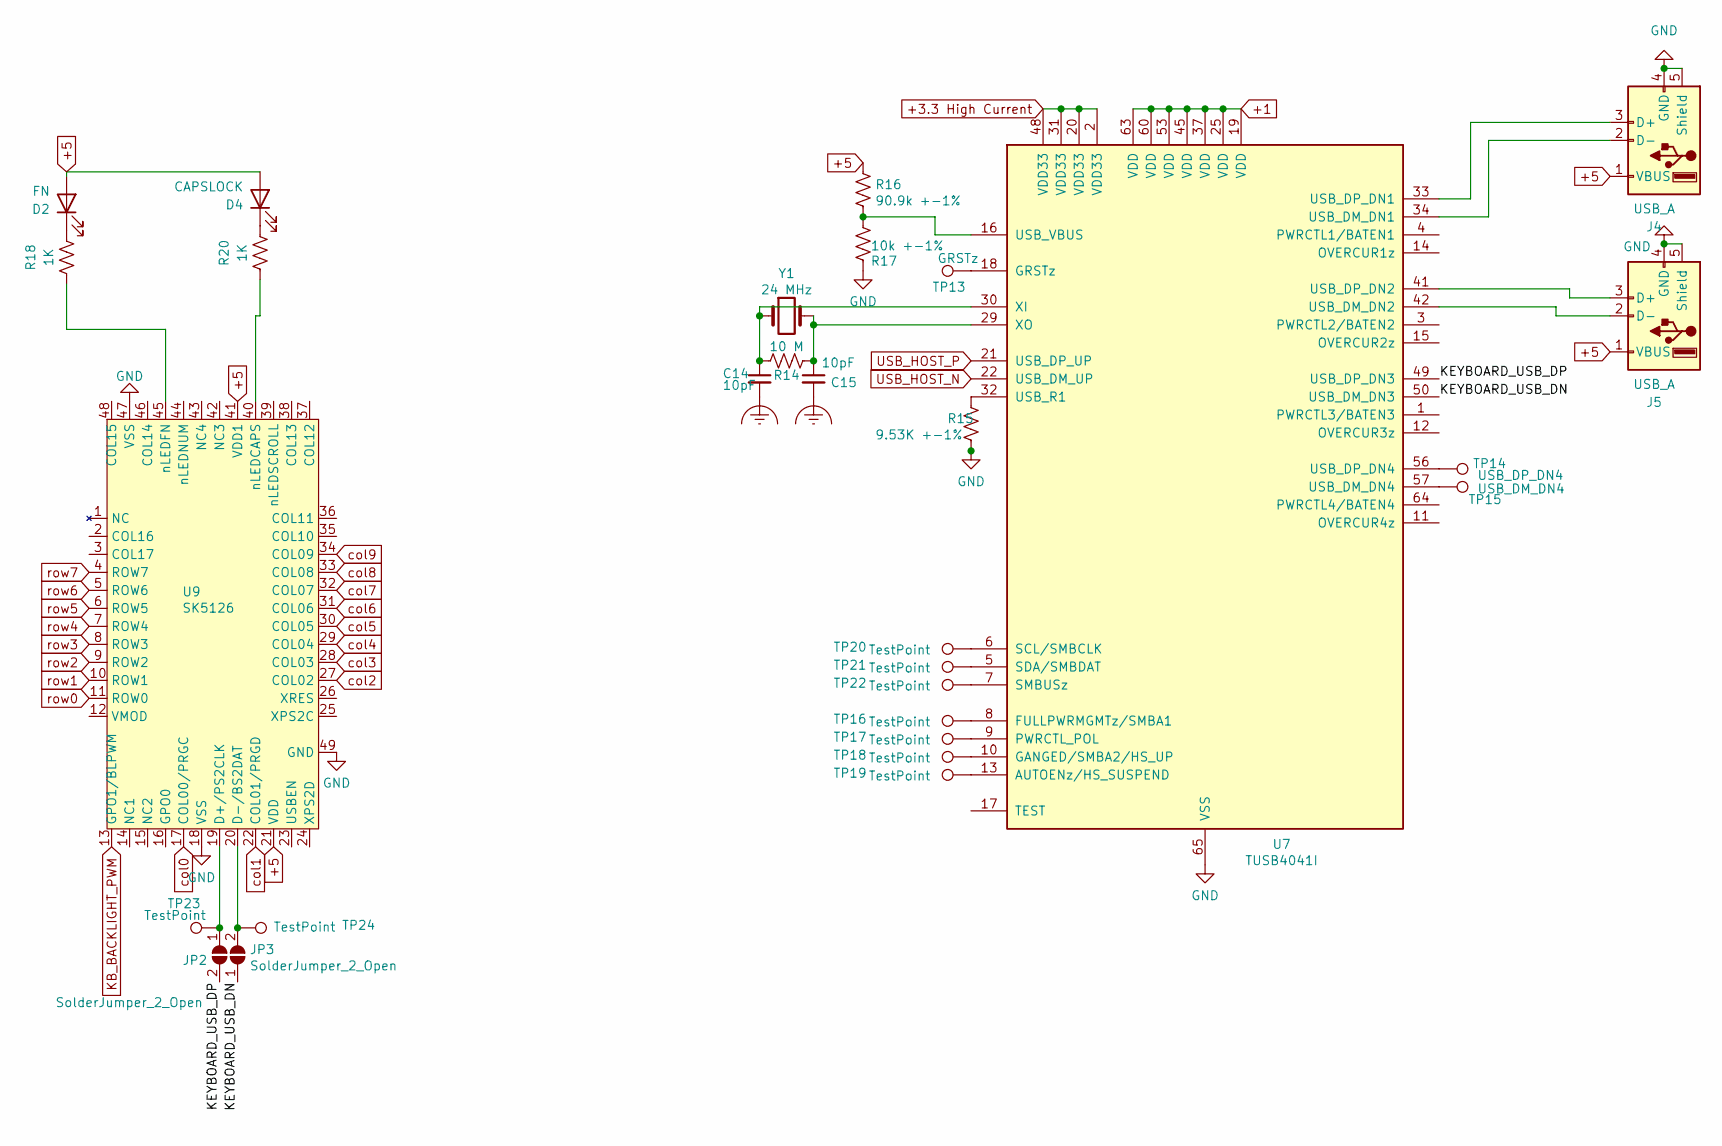
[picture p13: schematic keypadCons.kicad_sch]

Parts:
C14, C15: 10pF; C_1206_3216Metric
D2: FN; LED_1206_3216Metric_Pad1.42x1.75mm_HandSolder
D4: CAPSLOCK; LED_1206_3216Metric_Pad1.42x1.75mm_HandSolder
J4, J5: USB_A; USB_A_Stewart_SS-52100-001_Horizontal
JP2, JP3: SolderJumper_2_Open; SolderJumper-2_P1.3mm_Open_RoundedPad1.0x1.5mm
R14: 10 M; R_2010_5025Metric_Pad1.40x2.65mm_HandSolder
R15: 9.53K +-1%; R_2010_5025Metric_Pad1.40x2.65mm_HandSolder
R16: 90.9k +-1%; R_2010_5025Metric_Pad1.40x2.65mm_HandSolder
R17: 10k +-1%; R_2010_5025Metric_Pad1.40x2.65mm_HandSolder
R18, R20: 1K; R_1206_3216Metric
TP13: GRSTz; TestPoint_Pad_1.0x1.0mm
TP14: USB_DP_DN4; TestPoint_Pad_1.0x1.0mm
TP15: USB_DM_DN4; TestPoint_Pad_1.0x1.0mm
TP16, TP17, TP18, TP19, TP20, TP21, TP22, TP23, TP24: TestPoint; TestPoint_Pad_1.0x1.0mm
U7: TUSB4041I; HTQFP-64-1EP_10x10mm_P0.5mm_EP8x8mm_Mask4.4x4.4mm_ThermalVi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
U9: SK5126; QFN-48-1EP_7x7mm_P0.5mm_EP5.6x5.6mm
Y1: 24 MHz; HCM49_E

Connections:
+1: U7.19 (VDD), U7.25 (VDD), U7.37 (VDD), U7.45 (VDD), U7.53 (VDD), U7.60 (VDD), U7.63 (VDD); also elsewhere on the board
+3.3 High Current: U7.2 (VDD33), U7.20 (VDD33), U7.31 (VDD33), U7.48 (VDD33); also elsewhere on the board
+5: D2.2 (A), D4.2 (A), J4.1 (VBUS), J5.1 (VBUS), R16.1, U9.21 (VDD), U9.41 (VDD1); also elsewhere on the board
/USB and Keyboard connections/KEYBOARD_USB_DN: JP3.1 (A), U7.50 (USB_DM_DN3)
/USB and Keyboard connections/KEYBOARD_USB_DP: JP2.2 (B), U7.49 (USB_DP_DN3)
Earth_Clean: C14.2, C15.2, J4.4 (GND), J4.5 (Shield), J5.4 (GND), J5.5 (Shield), R15.2, R17.2, U7.46 (RSVD), U7.65 (VSS), U9.18 (VSS), U9.47 (VSS), U9.49 (GND); also elsewhere on the board
KB_BACKLIGHT_PWM: U9.13 (GPO1/BLPWM)
unnamed: C14.1, R14.2, U7.30 (XI), Y1.1
unnamed: C15.1, R14.1, U7.29 (XO), Y1.2
unnamed: D2.1 (K), R18.2
unnamed: D4.1 (K), R20.2
unnamed: J4.2 (D-), U7.34 (USB_DM_DN1)
unnamed: J4.3 (D+), U7.33 (USB_DP_DN1)
unnamed: J5.2 (D-), U7.42 (USB_DM_DN2)
unnamed: J5.3 (D+), U7.41 (USB_DP_DN2)
unnamed: JP2.1 (A), TP23.1, U9.19 (D+/PS2CLK)
unnamed: JP3.2 (B), TP24.1, U9.20 (D-/BS2DAT)
unnamed: R15.1, U7.32 (USB_R1)
unnamed: R16.2, R17.1, U7.16 (USB_VBUS)
unnamed: R18.1, U9.45 (nLEDFN)
unnamed: R20.1, U9.40 (nLEDCAPS)
unnamed: TP13.1, U7.18 (GRSTz)
unnamed: TP14.1, U7.56 (USB_DP_DN4)
unnamed: TP15.1, U7.57 (USB_DM_DN4)
unnamed: TP16.1, U7.8 (FULLPWRMGMTz/SMBA1)
unnamed: TP17.1, U7.9 (PWRCTL_POL)
unnamed: TP18.1, U7.10 (GANGED/SMBA2/HS_UP)
unnamed: TP19.1, U7.13 (AUTOENz/HS_SUSPEND)
unnamed: TP20.1, U7.6 (SCL/SMBCLK)
unnamed: TP21.1, U7.5 (SDA/SMBDAT)
unnamed: TP22.1, U7.7 (SMBUSz)
USB_HOST_N: U7.22 (USB_DM_UP); also elsewhere on the board
USB_HOST_P: U7.21 (USB_DP_UP); also elsewhere on the board
col0: U9.17 (COL00/PRGC); also elsewhere on the board
col1: U9.22 (COL01/PRGD); also elsewhere on the board
col2: U9.27 (COL02); also elsewhere on the board
col3: U9.28 (COL03); also elsewhere on the board
col4: U9.29 (COL04); also elsewhere on the board
col5: U9.30 (COL05); also elsewhere on the board
col6: U9.31 (COL06); also elsewhere on the board
col7: U9.32 (COL07); also elsewhere on the board
col8: U9.33 (COL08); also elsewhere on the board
col9: U9.34 (COL09); also elsewhere on the board
row0: U9.11 (ROW0); also elsewhere on the board
row1: U9.10 (ROW1); also elsewhere on the board
row2: U9.9 (ROW2); also elsewhere on the board
row3: U9.8 (ROW3); also elsewhere on the board
row4: U9.7 (ROW4); also elsewhere on the board
row5: U9.6 (ROW5); also elsewhere on the board
row6: U9.5 (ROW6); also elsewhere on the board
row7: U9.4 (ROW7); also elsewhere on the board

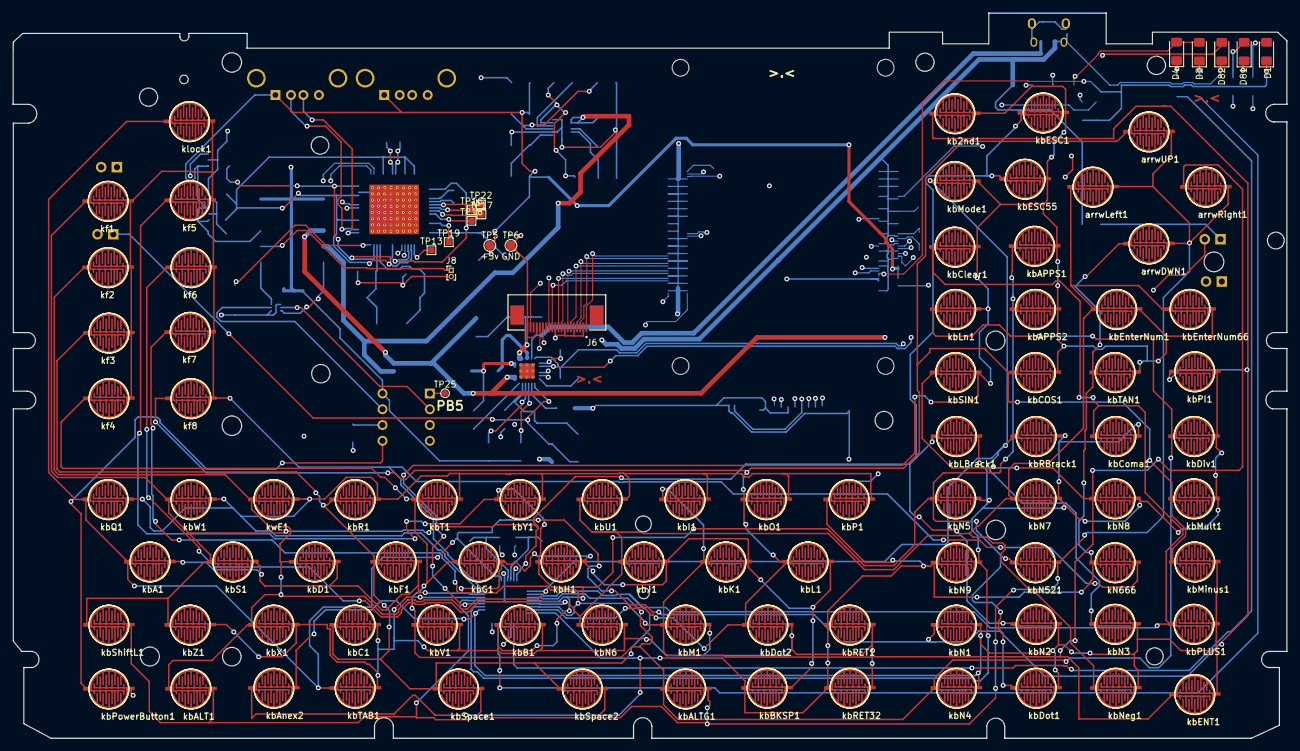
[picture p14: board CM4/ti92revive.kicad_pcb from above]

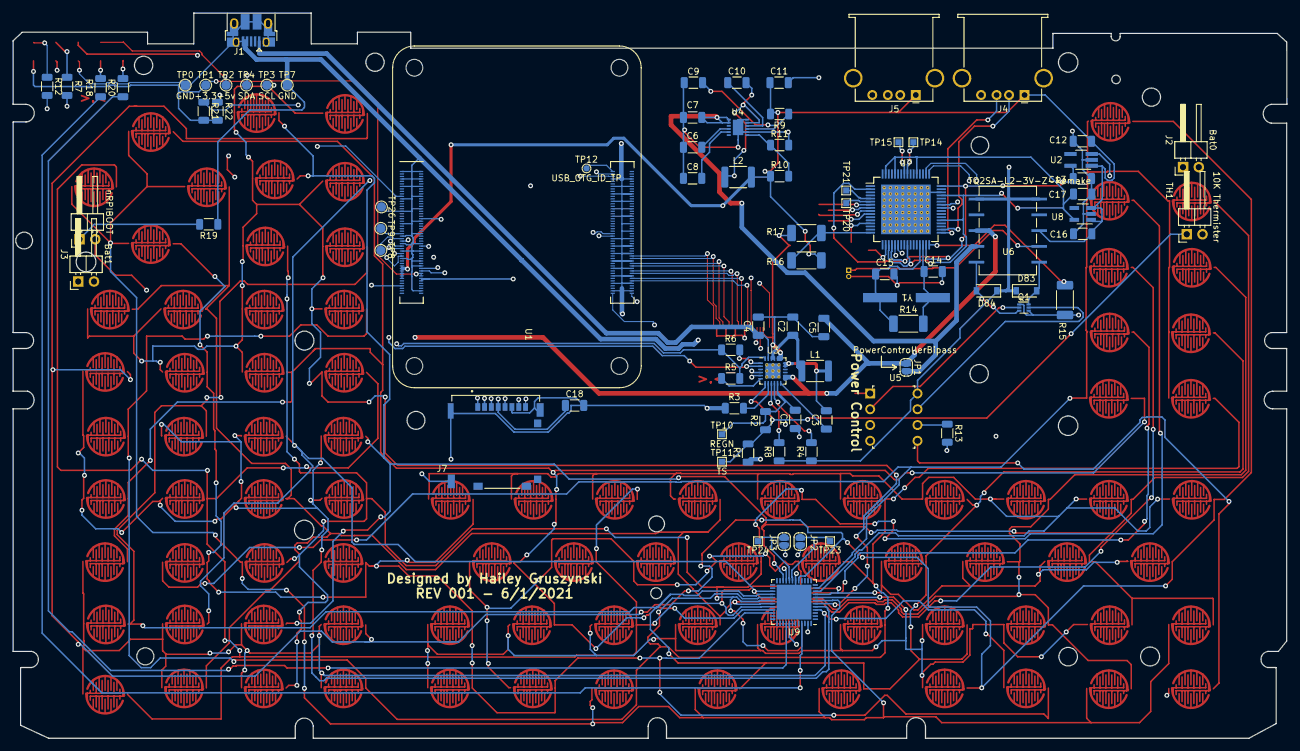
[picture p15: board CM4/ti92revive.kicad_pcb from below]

Board: 4 copper layers, 205.0 x 116.7 mm, 185 parts (84 on the bottom side), 112 nets.

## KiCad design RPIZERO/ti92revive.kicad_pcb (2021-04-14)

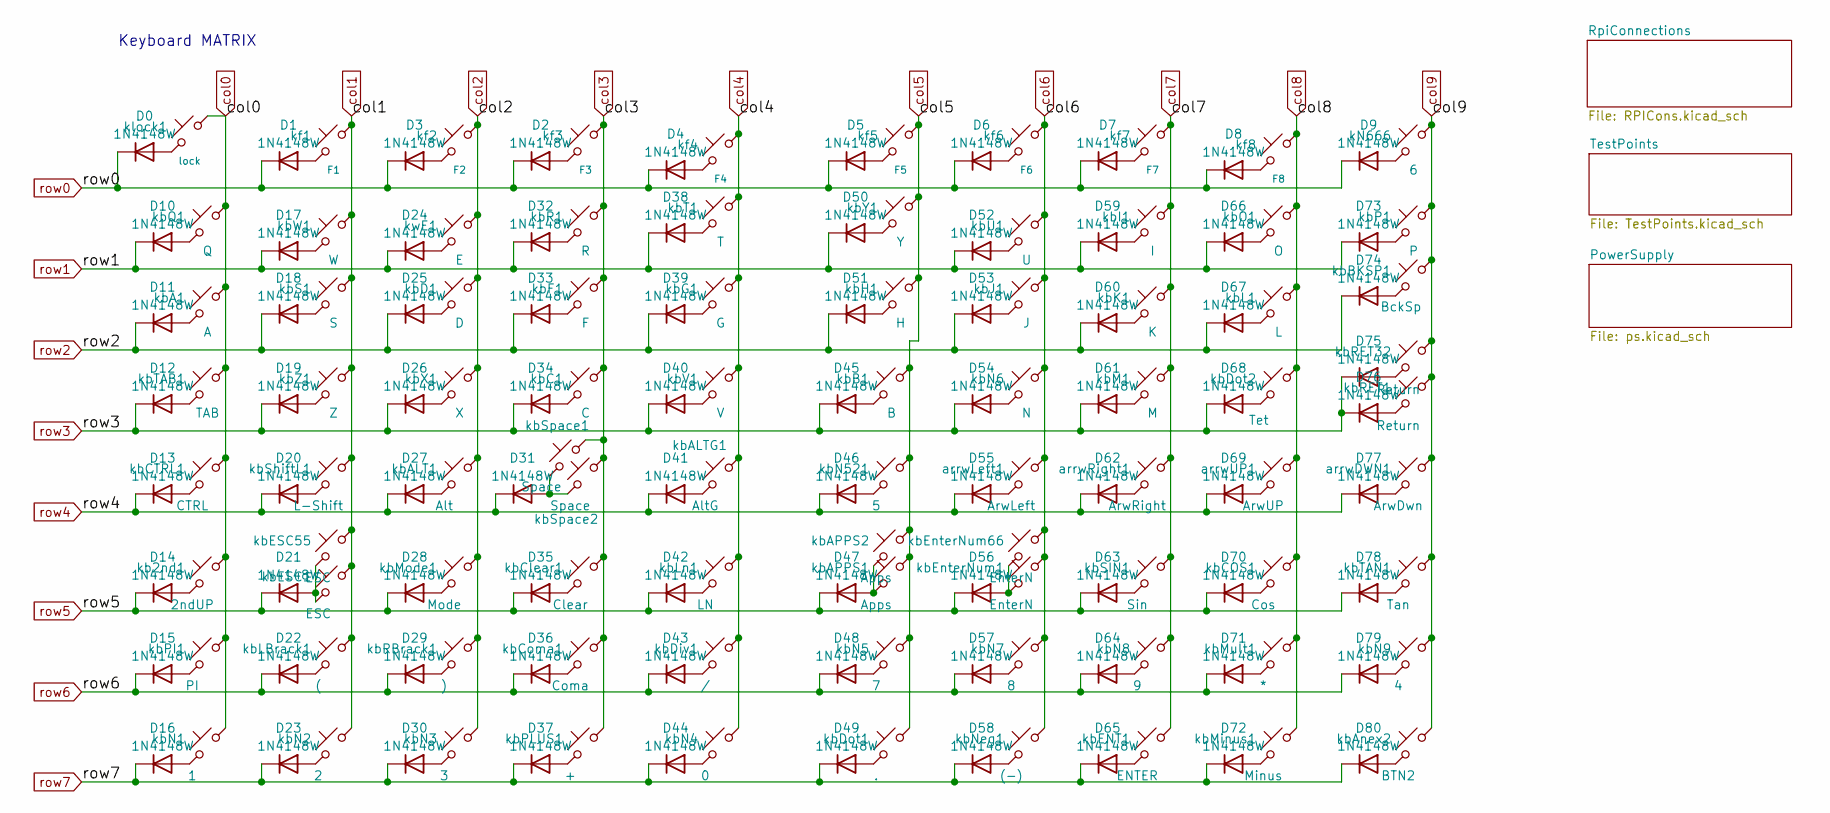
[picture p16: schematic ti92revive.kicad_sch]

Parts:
D0, D1, D2, D3, D4, D5, D6, D7, D8, D9, D10, D11, D12, D13, D14, D15, D16, D17, D18, D19, D20, D21, D22, D23, D24, D25, D26, D27, D28, D29, D30, D31, D32, D33, D34, D35, D36, D37, D38, D39, D40, D41, D42, D43, D44, D45, D46, D47, D48, D49, D50, D51, D52, D53, D54, D55, D56, D57, D58, D59, D60, D61, D62, D63, D64, D65, D66, D67, D68, D69, D70, D71, D72, D73, D74, D75, D76, D77, D78, D79, D80: 1N4148W; D_SOD-123
arrwDWN1: ArwDwn; SW_SPST_B3SL-1002P
arrwLeft1: ArwLeft; SW_SPST_B3SL-1002P
arrwRight1: ArwRight; SW_SPST_B3SL-1002P
arrwUP1: ArwUP; SW_SPST_B3SL-1002P
kN666: 6; Kbpad
kb2nd1: 2ndUP; SW_SPST_B3SL-1002P
kbA1: A; SW_SPST_B3SL-1002P
kbALT1: Alt; SW_SPST_B3SL-1002P
kbALTG1: AltG; SW_SPST_B3SL-1002P
kbAPPS1: Apps; SW_SPST_B3SL-1002P
kbAPPS2: Apps; Kbpad
kbAnex2: BTN2; Kbpad
kbB1: B; SW_SPST_B3SL-1002P
kbBKSP1: BckSp; SW_SPST_B3SL-1002P
kbC1: C; SW_SPST_B3SL-1002P
kbCOS1: Cos; SW_SPST_B3SL-1002P
kbCTRL1: CTRL; SW_SPST_B3SL-1002P
kbClear1: Clear; SW_SPST_B3SL-1002P
kbComa1: Coma; SW_SPST_B3SL-1002P
kbD1: D; SW_SPST_B3SL-1002P
kbDiv1: /; SW_SPST_B3SL-1002P
kbDot1: .; SW_SPST_B3SL-1002P
kbDot2: Tet; SW_SPST_B3SL-1002P
kbENT1: ENTER; SW_SPST_B3SL-1002P
kbESC1, kbESC55: ESC; SW_SPST_B3SL-1002P
kbEnterNum1, kbEnterNum66: EnterN; Kbpad
kbF1: F; SW_SPST_B3SL-1002P
kbG1: G; SW_SPST_B3SL-1002P
kbH1: H; SW_SPST_B3SL-1002P
kbI1: I; SW_SPST_B3SL-1002P
kbJ1: J; SW_SPST_B3SL-1002P
kbK1: K; SW_SPST_B3SL-1002P
kbL1: L; SW_SPST_B3SL-1002P
kbLBrack1: (; SW_SPST_B3SL-1002P
kbLn1: LN; SW_SPST_B3SL-1002P
kbM1: M; SW_SPST_B3SL-1002P
kbMinus1: Minus; Kbpad
kbMode1: Mode; SW_SPST_B3SL-1002P
kbMult1: *; SW_SPST_B3SL-1002P
kbN1: 1; SW_SPST_B3SL-1002P
kbN2: 2; SW_SPST_B3SL-1002P
kbN3: 3; SW_SPST_B3SL-1002P
kbN4: 0; SW_SPST_B3SL-1002P
kbN5: 7; SW_SPST_B3SL-1002P
kbN6: N; SW_SPST_B3SL-1002P
kbN7: 8; Kbpad
kbN8: 9; SW_SPST_B3SL-1002P
kbN9: 4; Kbpad
kbN521: 5; Kbpad
kbNeg1: (-); Kbpad
kbO1: O; SW_SPST_B3SL-1002P
kbP1: P; SW_SPST_B3SL-1002P
kbPI1: PI; SW_SPST_B3SL-1002P
kbPLUS1: +; SW_SPST_B3SL-1002P
kbQ1: Q; SW_SPST_B3SL-1002P
kbR1: R; SW_SPST_B3SL-1002P
kbRBrack1: ); SW_SPST_B3SL-1002P
kbRET1, kbRET32: Return; SW_SPST_B3SL-1002P
kbS1: S; SW_SPST_B3SL-1002P
kbSIN1: Sin; SW_SPST_B3SL-1002P
kbShiftL1: L-Shift; SW_SPST_B3SL-1002P
kbSpace1, kbSpace2: Space; SW_SPST_B3SL-1002P
kbT1: T; SW_SPST_B3SL-1002P
kbTAB1: TAB; SW_SPST_B3SL-1002P
kbTAN1: Tan; Kbpad
kbU1: U; SW_SPST_B3SL-1002P
kbV1: V; SW_SPST_B3SL-1002P
kbW1: W; SW_SPST_B3SL-1002P
kbX1: X; SW_SPST_B3SL-1002P
kbY1: Y; SW_SPST_B3SL-1002P
kbZ1: Z; SW_SPST_B3SL-1002P
kf1: F1; Kbpad
kf2: F2; Kbpad
kf3: F3; Kbpad
kf4: F4; SW_SPST_B3SL-1002P
kf5: F5; SW_SPST_B3SL-1002P
kf6: F6; SW_SPST_B3SL-1002P
kf7: F7; SW_SPST_B3SL-1002P
kf8: F8; SW_SPST_B3SL-1002P
klock1: lock; Kbpad
kwE1: E; SW_SPST_B3SL-1002P

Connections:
unnamed: D0.2 (A), klock1.2
unnamed: D1.2 (A), kf1.2
unnamed: D2.2 (A), kf3.2
unnamed: D3.2 (A), kf2.2
unnamed: D4.2 (A), kf4.2
unnamed: D5.2 (A), kf5.2
unnamed: D6.2 (A), kf6.2
unnamed: D7.2 (A), kf7.2
unnamed: D8.2 (A), kf8.2
unnamed: D9.2 (A), kN666.2
unnamed: D10.2 (A), kbQ1.2
unnamed: D11.2 (A), kbA1.2
unnamed: D12.2 (A), kbTAB1.2
unnamed: D13.2 (A), kbCTRL1.2
unnamed: D14.2 (A), kb2nd1.2
unnamed: D15.2 (A), kbPI1.2
unnamed: D16.2 (A), kbN1.2
unnamed: D17.2 (A), kbW1.2
unnamed: D18.2 (A), kbS1.2
unnamed: D19.2 (A), kbZ1.2
unnamed: D20.2 (A), kbShiftL1.2
unnamed: D21.2 (A), kbESC1.2, kbESC55.2
unnamed: D22.2 (A), kbLBrack1.2
unnamed: D23.2 (A), kbN2.2
unnamed: D24.2 (A), kwE1.2
unnamed: D25.2 (A), kbD1.2
unnamed: D26.2 (A), kbX1.2
unnamed: D27.2 (A), kbALT1.2
unnamed: D28.2 (A), kbMode1.2
unnamed: D29.2 (A), kbRBrack1.2
unnamed: D30.2 (A), kbN3.2
unnamed: D31.2 (A), kbSpace1.2, kbSpace2.2
unnamed: D32.2 (A), kbR1.2
unnamed: D33.2 (A), kbF1.2
unnamed: D34.2 (A), kbC1.2
unnamed: D35.2 (A), kbClear1.2
unnamed: D36.2 (A), kbComa1.2
unnamed: D37.2 (A), kbPLUS1.2
unnamed: D38.2 (A), kbT1.2
unnamed: D39.2 (A), kbG1.2
unnamed: D40.2 (A), kbV1.2
unnamed: D41.2 (A), kbALTG1.2
unnamed: D42.2 (A), kbLn1.2
unnamed: D43.2 (A), kbDiv1.2
unnamed: D44.2 (A), kbN4.2
unnamed: D45.2 (A), kbB1.2
unnamed: D46.2 (A), kbN521.2
unnamed: D47.2 (A), kbAPPS1.2, kbAPPS2.2
unnamed: D48.2 (A), kbN5.2
unnamed: D49.2 (A), kbDot1.2
unnamed: D50.2 (A), kbY1.2
unnamed: D51.2 (A), kbH1.2
unnamed: D52.2 (A), kbU1.2
unnamed: D53.2 (A), kbJ1.2
unnamed: D54.2 (A), kbN6.2
unnamed: D55.2 (A), arrwLeft1.2
unnamed: D56.2 (A), kbEnterNum1.2, kbEnterNum66.2
unnamed: D57.2 (A), kbN7.2
unnamed: D58.2 (A), kbNeg1.2
unnamed: D59.2 (A), kbI1.2
unnamed: D60.2 (A), kbK1.2
unnamed: D61.2 (A), kbM1.2
unnamed: D62.2 (A), arrwRight1.2
unnamed: D63.2 (A), kbSIN1.2
unnamed: D64.2 (A), kbN8.2
unnamed: D65.2 (A), kbENT1.2
unnamed: D66.2 (A), kbO1.2
unnamed: D67.2 (A), kbL1.2
unnamed: D68.2 (A), kbDot2.2
unnamed: D69.2 (A), arrwUP1.2
unnamed: D70.2 (A), kbCOS1.2
unnamed: D71.2 (A), kbMult1.2
unnamed: D72.2 (A), kbMinus1.2
unnamed: D73.2 (A), kbP1.2
unnamed: D74.2 (A), kbBKSP1.2
unnamed: D75.2 (A), kbRET32.2
unnamed: D76.2 (A), kbRET1.2
unnamed: D77.2 (A), arrwDWN1.2
unnamed: D78.2 (A), kbTAN1.2
unnamed: D79.2 (A), kbN9.2
unnamed: D80.2 (A), kbAnex2.2
col0: kb2nd1.1, kbA1.1, kbCTRL1.1, kbN1.1, kbPI1.1, kbQ1.1, kbTAB1.1, klock1.1; also elsewhere on the board
col1: kbESC1.1, kbESC55.1, kbLBrack1.1, kbN2.1, kbS1.1, kbShiftL1.1, kbW1.1, kbZ1.1, kf1.1; also elsewhere on the board
col2: kbALT1.1, kbD1.1, kbMode1.1, kbN3.1, kbRBrack1.1, kbX1.1, kf2.1, kwE1.1
col3: kbC1.1, kbClear1.1, kbComa1.1, kbF1.1, kbPLUS1.1, kbR1.1, kbSpace1.1, kbSpace2.1, kf3.1; also elsewhere on the board
col4: kbALTG1.1, kbDiv1.1, kbG1.1, kbLn1.1, kbN4.1, kbT1.1, kbV1.1, kf4.1; also elsewhere on the board
col5: kbAPPS1.1, kbAPPS2.1, kbB1.1, kbDot1.1, kbH1.1, kbN5.1, kbN521.1, kbY1.1, kf5.1; also elsewhere on the board
col6: arrwLeft1.1, kbEnterNum1.1, kbEnterNum66.1, kbJ1.1, kbN6.1, kbN7.1, kbNeg1.1, kbU1.1, kf6.1; also elsewhere on the board
col7: arrwRight1.1, kbENT1.1, kbI1.1, kbK1.1, kbM1.1, kbN8.1, kbSIN1.1, kf7.1; also elsewhere on the board
col8: arrwUP1.1, kbCOS1.1, kbDot2.1, kbL1.1, kbMinus1.1, kbMult1.1, kbO1.1, kf8.1; also elsewhere on the board
col9: arrwDWN1.1, kN666.1, kbAnex2.1, kbBKSP1.1, kbN9.1, kbP1.1, kbRET1.1, kbRET32.1, kbTAN1.1
row0: D0.1 (K), D1.1 (K), D2.1 (K), D3.1 (K), D4.1 (K), D5.1 (K), D6.1 (K), D7.1 (K), D8.1 (K), D9.1 (K); also elsewhere on the board
row1: D10.1 (K), D17.1 (K), D24.1 (K), D32.1 (K), D38.1 (K), D50.1 (K), D52.1 (K), D59.1 (K), D66.1 (K), D73.1 (K); also elsewhere on the board
row2: D11.1 (K), D18.1 (K), D25.1 (K), D33.1 (K), D39.1 (K), D51.1 (K), D53.1 (K), D60.1 (K), D67.1 (K), D74.1 (K); also elsewhere on the board
row3: D12.1 (K), D19.1 (K), D26.1 (K), D34.1 (K), D40.1 (K), D45.1 (K), D54.1 (K), D61.1 (K), D68.1 (K), D75.1 (K), D76.1 (K); also elsewhere on the board
row4: D13.1 (K), D20.1 (K), D27.1 (K), D31.1 (K), D41.1 (K), D46.1 (K), D55.1 (K), D62.1 (K), D69.1 (K), D77.1 (K); also elsewhere on the board
row5: D14.1 (K), D21.1 (K), D28.1 (K), D35.1 (K), D42.1 (K), D47.1 (K), D56.1 (K), D63.1 (K), D70.1 (K), D78.1 (K); also elsewhere on the board
row6: D15.1 (K), D22.1 (K), D29.1 (K), D36.1 (K), D43.1 (K), D48.1 (K), D57.1 (K), D64.1 (K), D71.1 (K), D79.1 (K); also elsewhere on the board
row7: D16.1 (K), D23.1 (K), D30.1 (K), D37.1 (K), D44.1 (K), D49.1 (K), D58.1 (K), D65.1 (K), D72.1 (K), D80.1 (K); also elsewhere on the board

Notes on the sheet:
Keyboard MATRIX

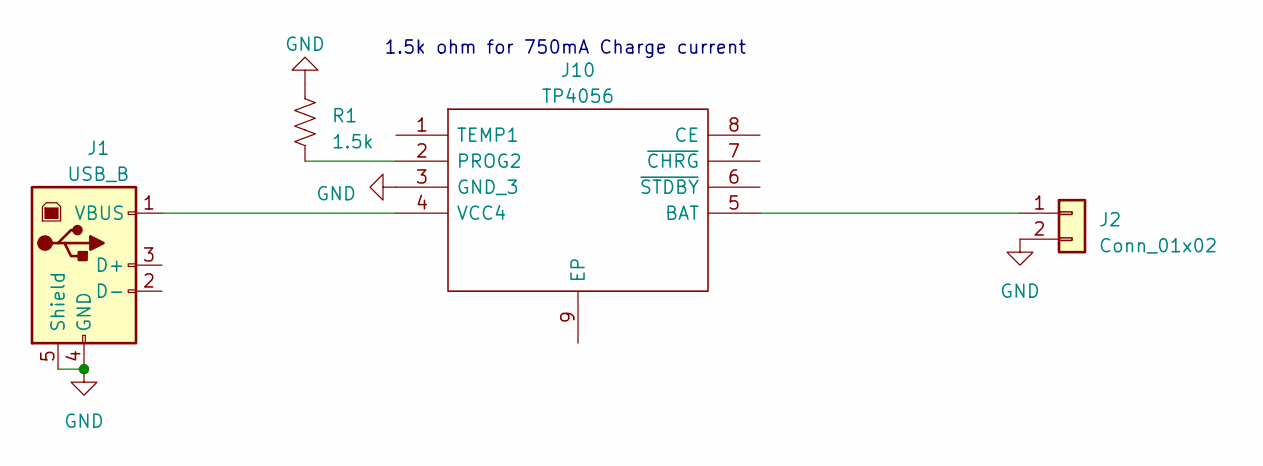
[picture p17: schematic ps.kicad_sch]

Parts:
J1: USB_B; USB_Micro-B_Amphenol_10103594-0001LF_Horizontal
J2: Conn_01x02; JST_PH_B2B-PH-K_1x02_P2.00mm_Vertical
J10: TP4056; SOIC127P600X175-9N; Manufacturer_Part_Number TP4056
R1: 1.5k; R_2010_5025Metric

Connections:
GND: J1.4 (GND), J1.5 (Shield), J2.2, J10.3 (GND_3), R1.2; also elsewhere on the board
unnamed: J1.1 (VBUS), J10.4 (VCC4)
unnamed: J10.2 (PROG2), R1.1
unnamed: J2.1, J10.5 (BAT)

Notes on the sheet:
1.5k ohm for 750mA Charge current

Board: 2 copper layers, 179 parts (92 on the bottom side), 107 nets, no tracks yet.

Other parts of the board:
RPI0: ADA3708; ADA3708_RPI-ZERO
TP0, TP6: GND; TestPoint_Pad_D1.5mm
TP1: +3.3; TestPoint_Pad_D1.5mm
TP2, TP5: +5v; TestPoint_Pad_D1.5mm
TP3: SCL; TestPoint_Pad_D1.5mm
TP4: SDA; TestPoint_Pad_D1.5mm
U1: Teensy++2.0_(Arduino); Teensy2.0++

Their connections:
+3.3: RPI0.17 (3V3[2]), TP1.1
+5: RPI0.2 (5V[1]), TP2.1, TP5.1
GND: RPI0.39 (GND[3]), TP0.1, TP6.1, U1.1 (GND); also elsewhere on the board
SCL: RPI0.5 (GPIO3/SCL), TP3.1, U1.3 (0_INT0_PWM)
SDA: RPI0.3 (GPIO2/SDA), TP4.1, U1.4 (1_INT1_PWM)
col0: U1.36 (20); also elsewhere on the board
col1: U1.37 (21); also elsewhere on the board
col3: U1.38 (22); also elsewhere on the board
col4: U1.39 (23); also elsewhere on the board
col5: U1.44 (28); also elsewhere on the board
col6: U1.45 (29); also elsewhere on the board
col7: U1.46 (30); also elsewhere on the board
col8: U1.47 (31); also elsewhere on the board
row0: U1.7 (4); also elsewhere on the board
row1: U1.8 (5); also elsewhere on the board
row2: U1.10 (7); also elsewhere on the board
row3: U1.11 (8); also elsewhere on the board
row4: U1.12 (9); also elsewhere on the board
row5: U1.13 (10); also elsewhere on the board
row6: U1.14 (11); also elsewhere on the board
row7: U1.15 (12); also elsewhere on the board

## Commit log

2021-04-13 Adding Stuff to the project
    Yee, doing it
    [RPICons.kicad_sch, TestPoints.kicad_sch, bom.xlsx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]
2021-04-14 Clean up and resetting to do the compute modual version
    [PickingTheDisplay.ods, RPICons.kicad_sch, TestPoints.kicad_sch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]
2021-04-14 Push before big change
    Chaing the charge controll Stuffs
    [RPICons.kicad_sch, TestPoints.kicad_sch, bom.xlsx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]
2021-04-14 Working on adding new charge controller
    [ps.kicad_sch, ti92revive.kicad_pcb, ti92revive.kicad_sch]
2021-04-15 BatteryCharging COMPLEATE
    [bom.xlsx, ps.kicad_sch, ti92revive.kicad_sch]
2021-04-15 Laid out 5v ic and battery charger
    [ps.kicad_sch, ti92revive.kicad_pcb, ti92revive.kicad_sch]
2021-04-15 Added Power Button Control Circuit
    [RoutingCheck.dsn, bom.xlsx, ps.kicad_sch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]
2021-04-16 Added Power Control Relay
    also cleaned up some junk and jank
    [RPICons.kicad_sch, bom.xlsx, ps.kicad_sch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]
2021-04-16 Wrote program discription
    [ps.kicad_sch, ti92revive.kicad_pcb]
2021-04-16 Removed Keyboard Matrix Diodes and Added PowerLED and ActivityLED
    [RPICons.kicad_sch, bom.xlsx, ps.kicad_sch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]
2021-04-16 Added Keyboard Matrix Map
    [KeyboardMatrixMap.xlsx]
2021-04-17 Added high current 3.3v supply
    [KeyboardMatrixMap.xlsx, RPICons.kicad_sch, bom.xlsx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]
2021-04-19 Added USB Hub Contoler and usb port internal and external
    [RPICons.kicad_sch, bom.xlsx, keypadCons.kicad_sch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]
2021-04-19 Added Keyboard matrix controller and indicator leds
    [RPICons.kicad_sch, keypadCons.kicad_sch, ps.kicad_sch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]
2021-04-19 Cleaned Up the Matrix contolller
    [keypadCons.kicad_sch, ps.kicad_sch, ti92revive.kicad_pcb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]
2021-04-19 added battery connecoectors and emmcbootdisable jumpper
    [RPICons.kicad_sch, ps.kicad_sch, ti92revive.kicad_pcb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]
2021-04-20 Finally Added the display!!!!
    [RPICons.kicad_sch, bom.xlsx, display.kicad_sch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]
2021-04-21 Started the "fun" of routing
    [RPICons.kicad_sch, RoughTryREV1.dsn, RoughTryREV2.dsn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]
2021-04-21 i hate routing
    [ti92revive.kicad_pcb, ti92revive.kicad_sch]
2021-04-21 Heck Routing
    [ti92revive.kicad_pcb]
2021-04-21 Wow, This is kinda fun
    [ti92revive.kicad_pcb]
2021-04-21 More wires hehehehe
    wow so good
    [ti92revive.kicad_pcb]
2021-04-21 Keyboard close to done
    [ti92revive.kicad_pcb]
2021-04-21 Keyboard Done <3
    adding a layer for signals that need to be *Clean*
    [ti92revive.kicad_pcb]
2021-04-21 boys we got 2 more layers to play with now >.<
    (oh god this is so much stuff hehehehehehe.... ima go mad with power)
    [ti92revive.kicad_pcb]
2021-04-21 routing fun!!
    [ti92revive.kicad_pcb]
2021-04-21 100 things left to rout
    [ti92revive.kicad_pcb]
2021-04-21 75 left to go
    [ti92revive.kicad_pcb]
2021-04-21 Everything is routed
    Just waiting on display to finsh routing that, then its time to get some pcbs on the way and cross my fingers that i dont cook a cm4 >.<
    [ps.kicad_sch, ti92revive.kicad_pcb, ti92revive.kicad_sch]
2021-04-21 Adding image for readme
    [RPICons.kicad_sch, TestPoints.kicad_sch, ti92revive.kicad_sch]
2021-05-28 Bigone here we go
    Whats gonna happon is im gonna get a 4 inch hdmi display and desolder the hdmi connector and add it to a ribbion cable and then add a connector to the pcb for hdmi to interface with that
    [RPICons.kicad_sch, bom.xlsx, display.kicad_sch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]
2021-05-31 adding hdmi connector
    [RPICons.kicad_sch, display.kicad_sch, ti92revive.kicad_pcb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]
2021-05-31 Removed Jumpers and just doing hdmi the right way the first time, this wont bite me in the butt
    [display.kicad_sch, ti92revive.kicad_sch]
2021-06-01 added sdcard
    [RPICons.kicad_sch, SDCard.kicad_sch, bom.xlsx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]
2021-06-02 display done
    [RPICons.kicad_sch, SDCard.kicad_sch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]
2021-06-02 Compleated REV001
    [bom.xlsx, display.kicad_sch, ps.kicad_sch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]
2021-06-02 no more uvias
    [ti92revive-B_Cu.gbr, ti92revive-B_Fab.gbr, ti92revive-B_Mask.gbr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]

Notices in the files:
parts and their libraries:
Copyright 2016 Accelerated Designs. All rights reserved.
